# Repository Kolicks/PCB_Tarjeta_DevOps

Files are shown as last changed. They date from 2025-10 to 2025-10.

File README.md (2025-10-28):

# ⚙️ PCB_Tarjeta_DevOps
**Generic Development Console with Ethernet and USB Connectivity**

---

<p align="center">
  <a href="https://github.com/Kolicks/PCB_Tarjeta_DevOps" target="_blank">
    
  </a>
</p>

---

## 📘 Overview
**PCB_Tarjeta_DevOps** is a versatile, custom-designed console PCB created primarily as a **personal exercise in complex two-layer design and Ethernet integration**.  
It serves as a **general-purpose development board** adapted from the **ST Nucleo-F412ZG** design, focusing on practical layout challenges and signal-integrity learning (Ethernet, differential pairs, impedance control).

<p align="center">
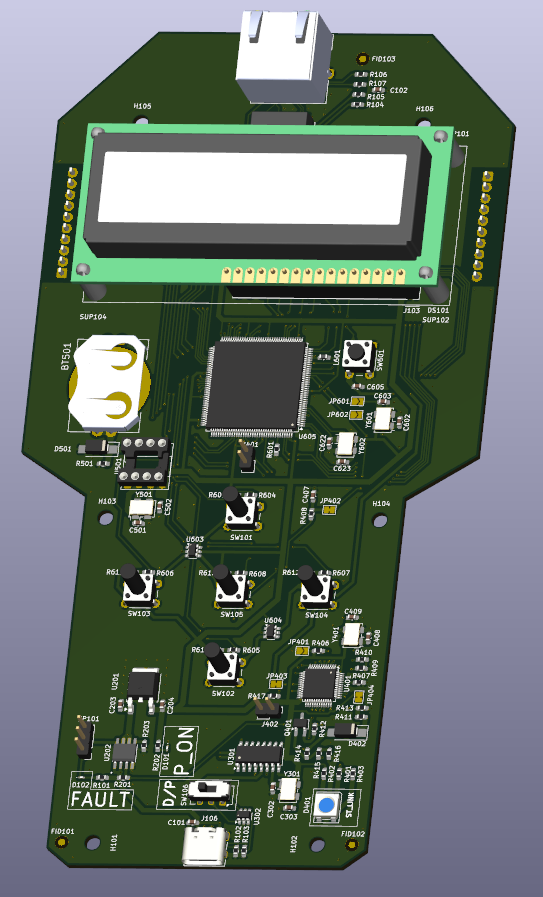
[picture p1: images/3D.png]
3D Top
  
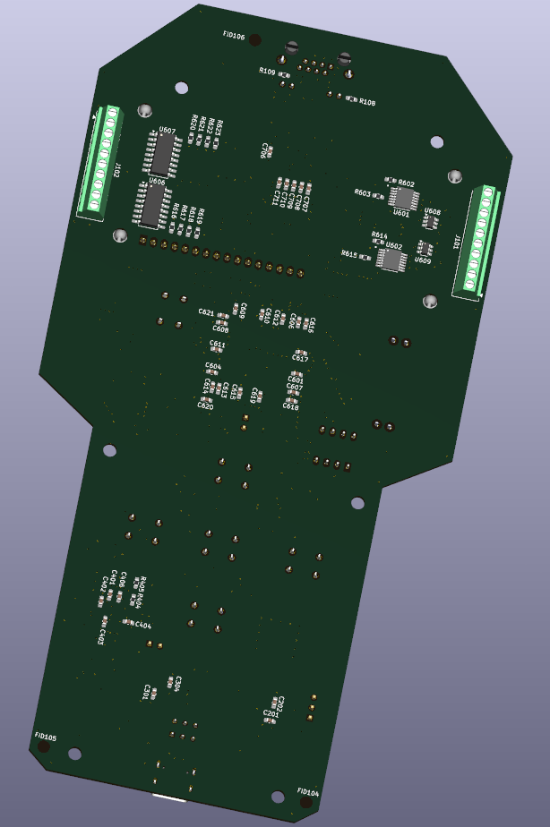
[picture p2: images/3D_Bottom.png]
3D Bottom
  
  <br>
  <em>3D renders of the PCB_Tarjeta_DevOps — Top and Bottom views</em>
</p>

---

## ⚙️ General Information
- A **general-purpose console**, not intended for a specific application.  
- Designed as a **learning exercise**, implementing many components on only **two layers** to increase design difficulty.  
- Served as an **introduction to Ethernet PCB layout**, including **differential pair routing** and **impedance control**.  
- Several schematic blocks were **adapted from the ST Nucleo-F412ZG** for familiarity and reference.  

<p align="center">
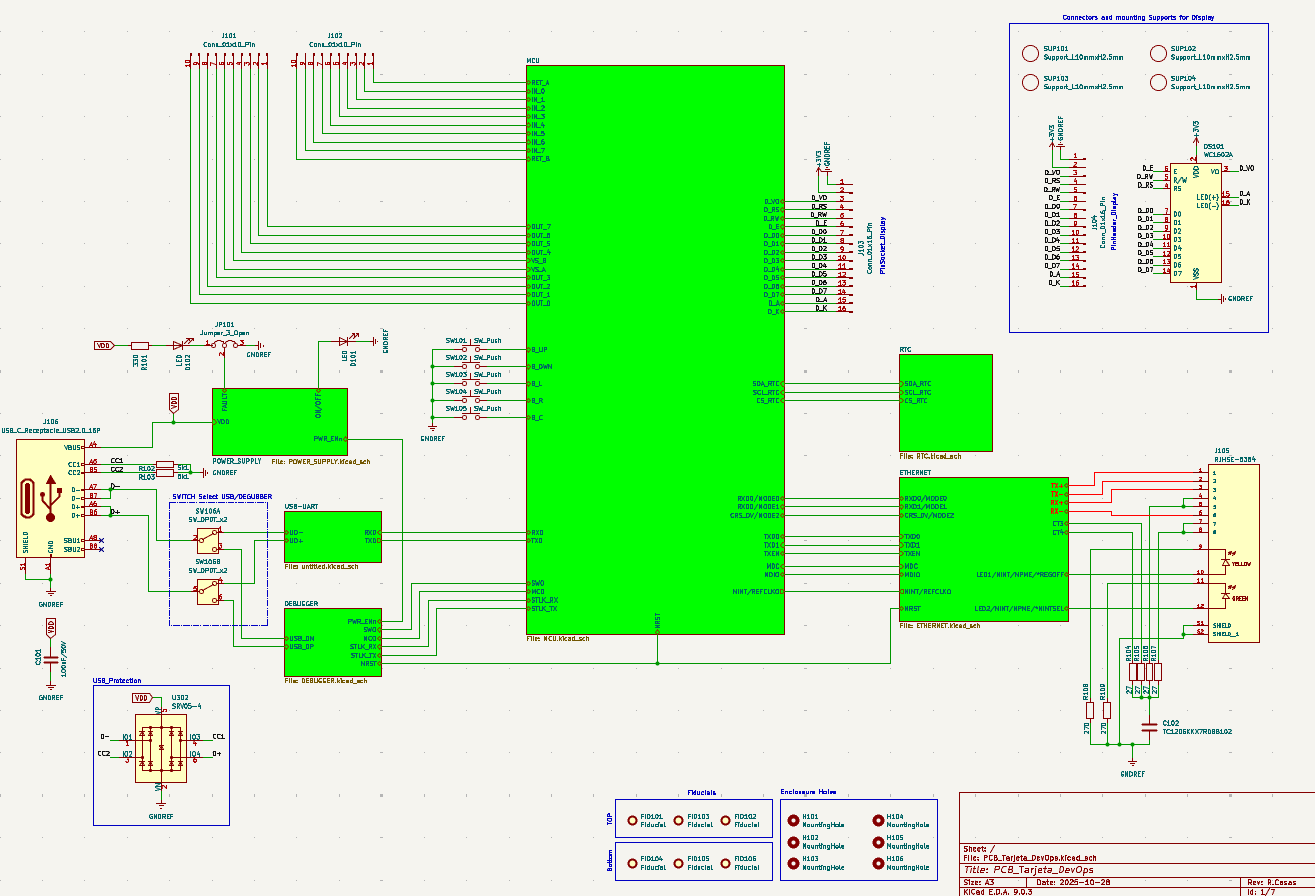
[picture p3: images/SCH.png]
Schematic
  
  <br>
  <em>Full schematic diagram of the PCB_Tarjeta_DevOps (KiCad 9)</em>
</p>

---

## 🔧 Characteristics
- Acts as a **multi-purpose development console**.  
- Supports **USB power and programming**.  
- Integrates **Ethernet connectivity** with differential pair routing and impedance matching.  
- Includes **8 Inputs and 8 Outputs**:  
  - **Outputs for industrial/power use** driven by **ITS4090QEPDXUMA1** — up to **1.5 A** each, suitable for **24 V industrial control**.  
  - **8 isolated outputs** using **TLP290-4** optocouplers (potential-free, up to 24 V).  
- Features a **hardware switch selector** to toggle between **programming** and **debugging** modes.  
- Includes a **real-time clock (RTC)** with **CR2032 battery backup**.  
- Provides **five tactile buttons** for user interaction with the display or user interface.  

<p align="center">
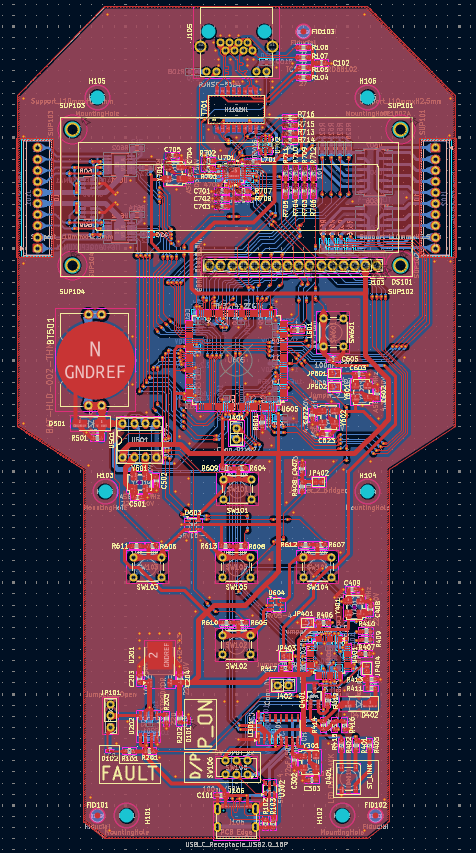
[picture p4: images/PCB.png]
PCB Layout
  
  <br>
  <em>Top layer routing and overall PCB layout (KiCad 9)</em>
</p>

---

## ⚠️ Design Notes
- **Display Section:**  
  - Multiple components in the display area require mechanical supports and connectors.  
  - Some footprints should be marked as **DNP (Do Not Populate)** and clearly specified for **DFM/DFA** purposes.  
- **Ethernet Interface:**  
  - Differential pairs are **impedance-matched to 100 Ω**, validated using **JLCPCB’s impedance calculator** and fabrication stack-up data.  
  - **USB traces** are not impedance-controlled in this revision (planned improvement).  
- **DFM Analysis (JLCPCB DFM tool):**  
  - Found **drilling overlaps** in display-related holes (mechanical supports and signals).  
  - **USB-C footprint issue:** plated hole size **0.60 mm, required >0.61 mm** tolerance.  
- **Silkscreen and Drill Issues:**  
  - Some silkscreen elements **collide with through holes** but remain legible.  
  - **Line width warnings** flagged for narrow silkscreen traces — minor fabrication risk, acceptable in prototype runs.  
- Overall design remains **manufacturable** and **functionally valid**, despite minor DFM flags.  

---

## 🧩 Repository Structure
PCB_Tarjeta_DevOps/

├── schematic/ # KiCad schematic files

├── pcb_layout/ # KiCad PCB layout files

├── gerbers/ # Gerber fabrication files

├── images/ # Rendered visuals (3D, SCH, PCB)

├── LICENSE # Hardware license (CERN-OHL-P v2.0)

└── README.md # Project documentation

---

## 📜 License
This hardware design is released under the **CERN Open Hardware License v2 – Permissive (CERN-OHL-P-2.0)**.  
You are free to use, modify, and distribute this design, provided that:
- The license is included with redistributions.
- Proper credit is given to the original author.

More info: https://cern-ohl.web.cern.ch/

---

## 👤 Author
**Project:** PCB_Tarjeta_DevOps  
**Author:** [Kolicks]  
**Toolchain:** KiCad 9  
**Version:** 9.0  

---

## 🧱 Future Improvements
- Redesign **USB differential pair** routing with impedance control.  
- Correct **DFM-related drilling and silkscreen** warnings.  
- Mark **DNP parts** for display connectors and update BOM.

---

⭐ *If you find this project useful or educational, please consider starring the repository and sharing feedback!*

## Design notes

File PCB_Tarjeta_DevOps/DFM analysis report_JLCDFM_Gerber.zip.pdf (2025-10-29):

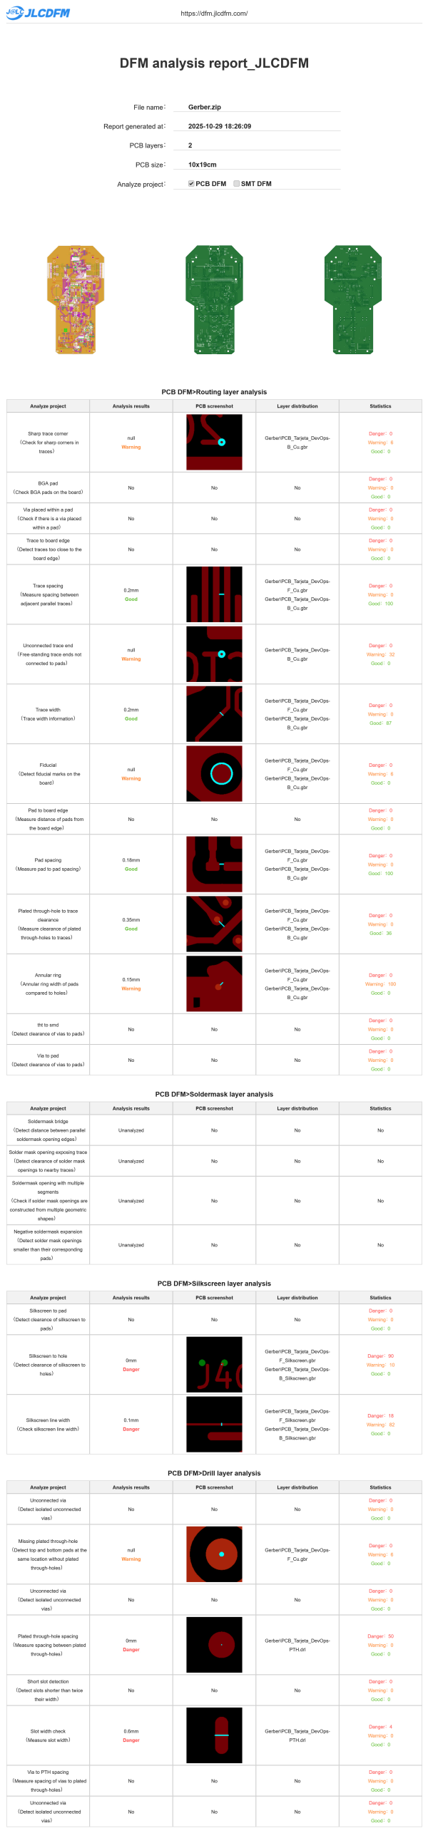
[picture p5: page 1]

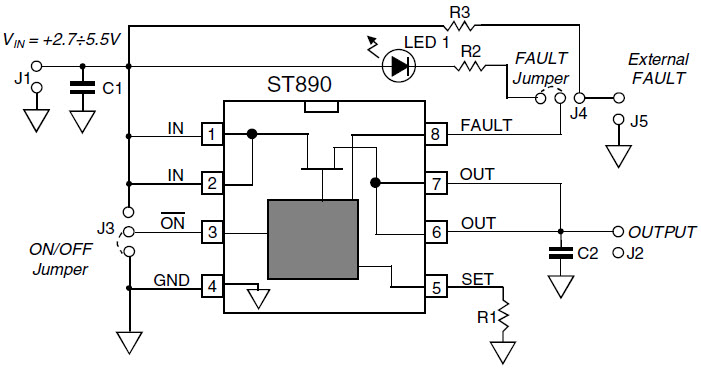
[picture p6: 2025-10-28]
PCB_Tarjeta_DevOps/Datasheets/an1441_fig.13.jpg

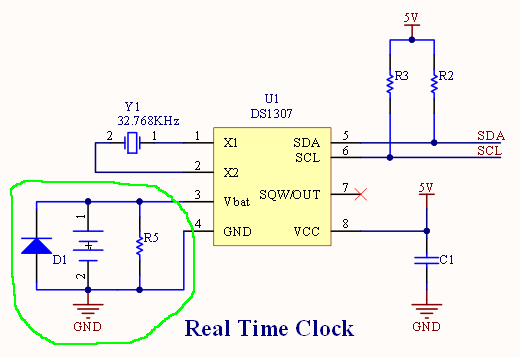
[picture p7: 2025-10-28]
PCB_Tarjeta_DevOps/Datasheets/8383d035b52fffc298dc10fdf3a309924005adde.png

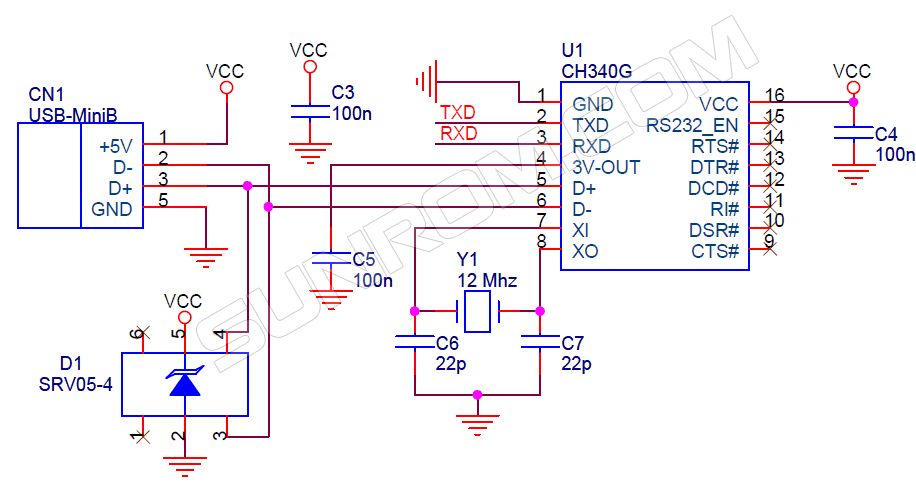
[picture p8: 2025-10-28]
PCB_Tarjeta_DevOps/Datasheets/ch340.gif

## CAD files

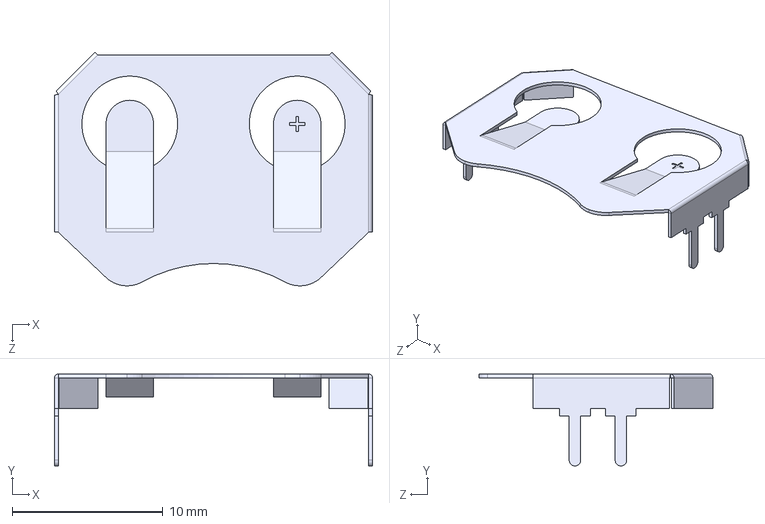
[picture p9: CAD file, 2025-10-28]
PCB_Tarjeta_DevOps/Footprints/BAT_HLD_002_THM/BAT-HLD-002-THM.step
21.1 x 6.10 x 15.5 mm

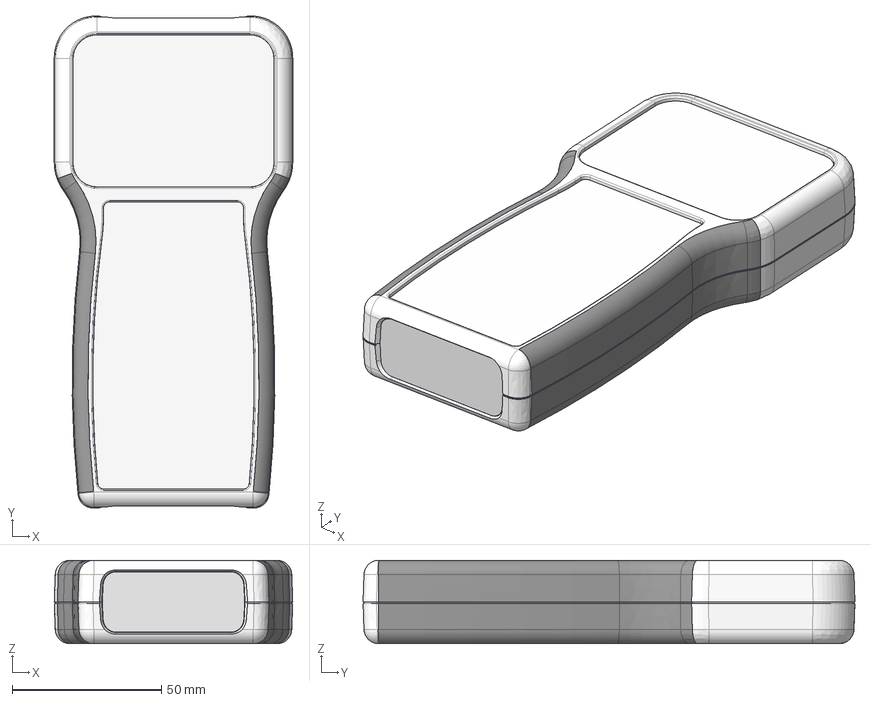
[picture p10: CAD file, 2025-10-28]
PCB_Tarjeta_DevOps/Footprints/Box_1553TTBK/1553TT.stp
80.0 x 165.0 x 28.0 mm
1553TT BOTTOM
1553TT TOP
1553TT FRONT PANEL x 2
1553TT PCB
SC501 (screw M3-0.5X 18mm FH) x 6
M3 PLASTIC INSERT (SERIES 19 LONG) x 6
1553TT TOP GRIP
1553TT BOTTOM GRIP

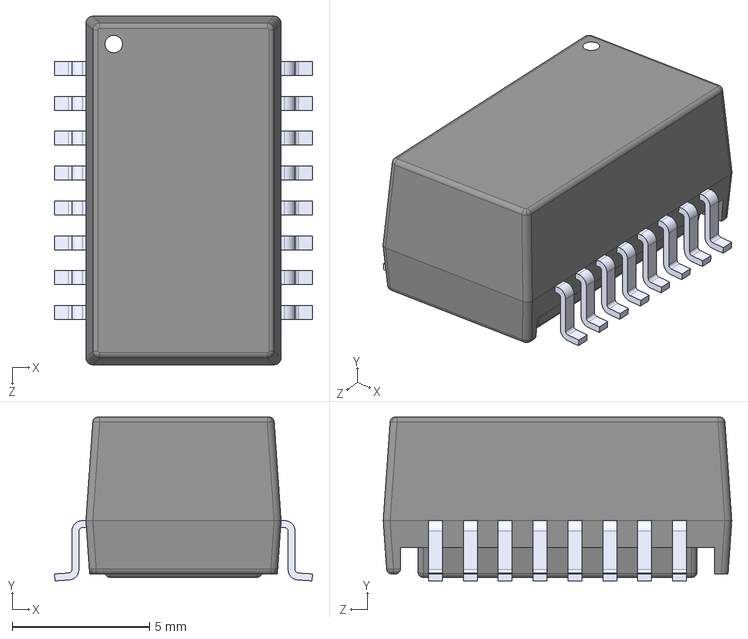
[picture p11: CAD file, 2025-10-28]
PCB_Tarjeta_DevOps/Footprints/H1102NL/H1102NL.step
9.40 x 5.97 x 12.7 mm

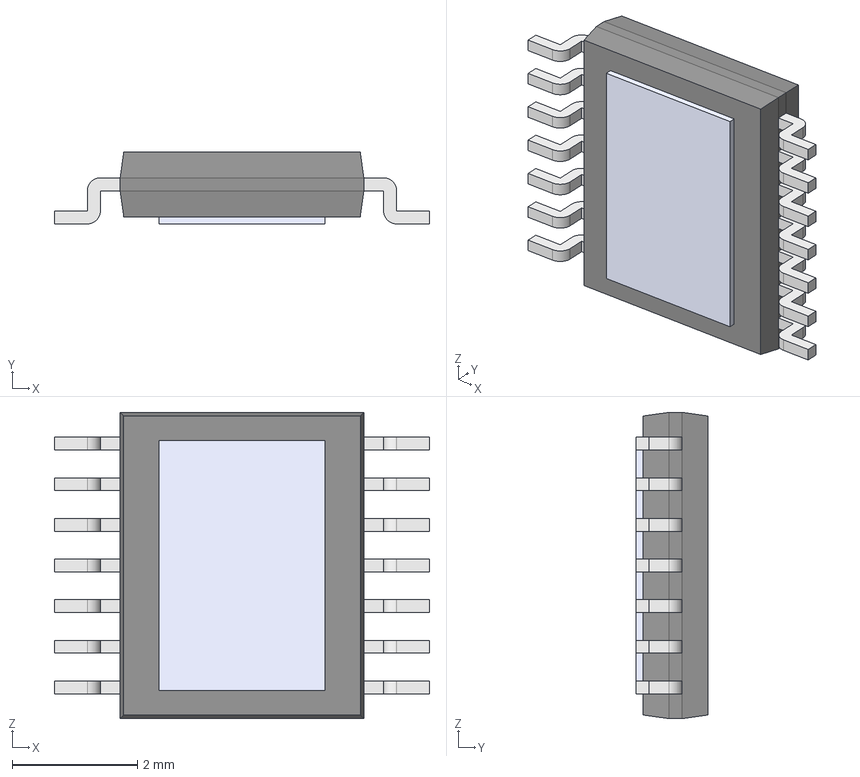
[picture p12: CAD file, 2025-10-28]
PCB_Tarjeta_DevOps/Footprints/ITS4090QEPDXUMA1/ITS4090QEPDXUMA1.step
6.00 x 1.15 x 4.90 mm
Body001 (Mirror #1) x 7
XY-plane x 12
X-axis x 12

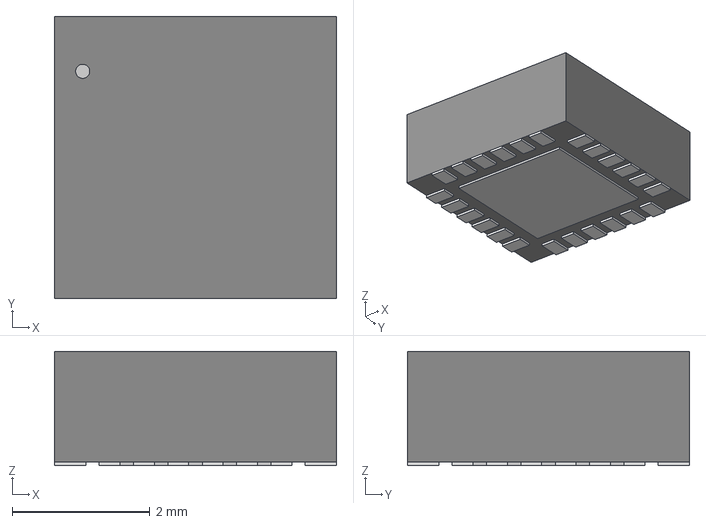
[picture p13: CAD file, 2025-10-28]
PCB_Tarjeta_DevOps/Footprints/LAN8742A_CZ_TR/SQFN24_4X4MC_MCH.step
4.09 x 4.09 x 1.65 mm

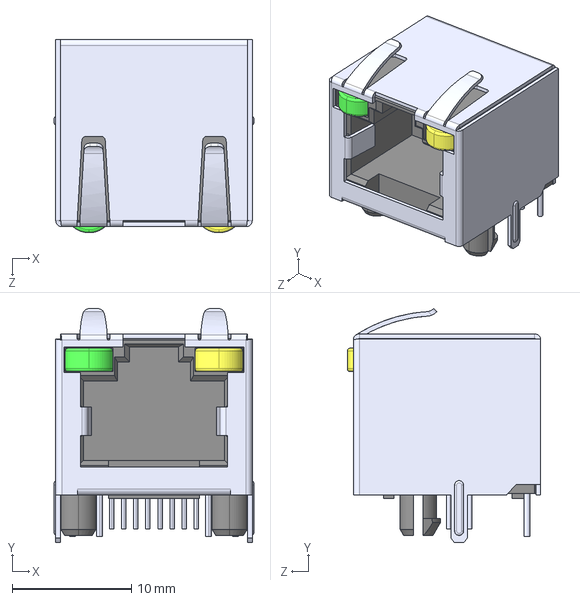
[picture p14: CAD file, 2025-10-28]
PCB_Tarjeta_DevOps/Footprints/RJHSE5384/RJHSE-5384.step
16.8 x 19.7 x 16.3 mm

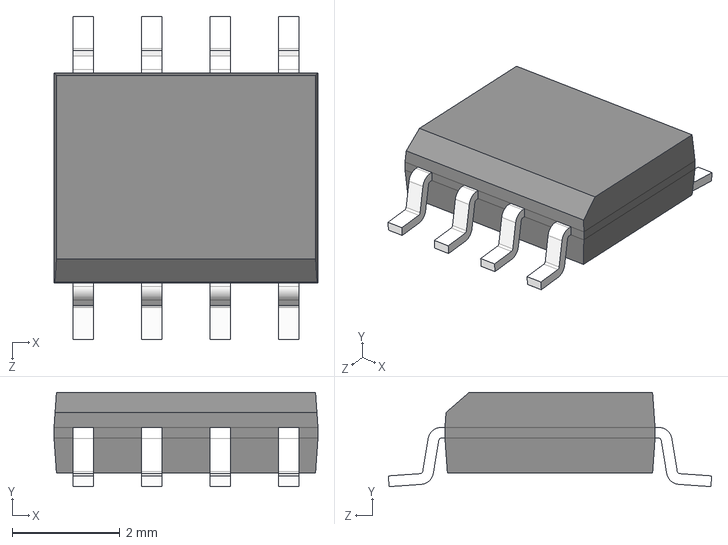
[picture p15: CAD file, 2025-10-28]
PCB_Tarjeta_DevOps/Footprints/ST890CDR/ST890CDR.step
4.90 x 1.75 x 6.00 mm

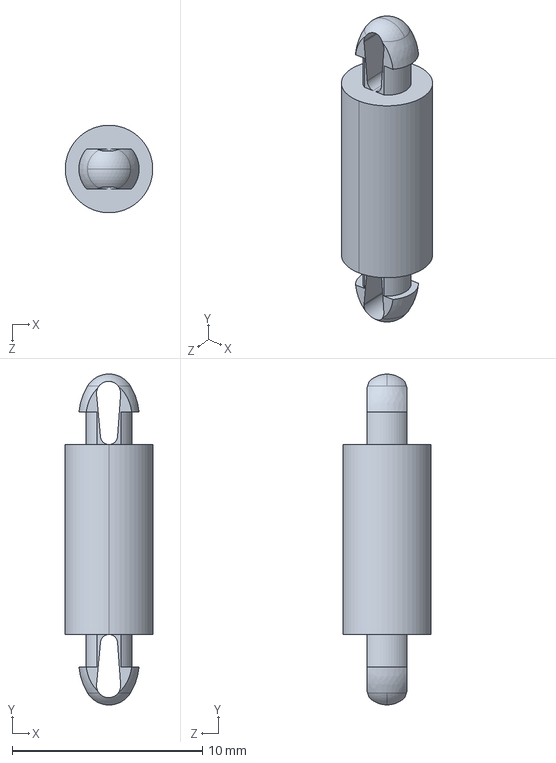
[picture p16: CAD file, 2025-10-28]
PCB_Tarjeta_DevOps/Footprints/MDLSP1_10M_01/10015254.step
4.60 x 17.4 x 4.60 mm

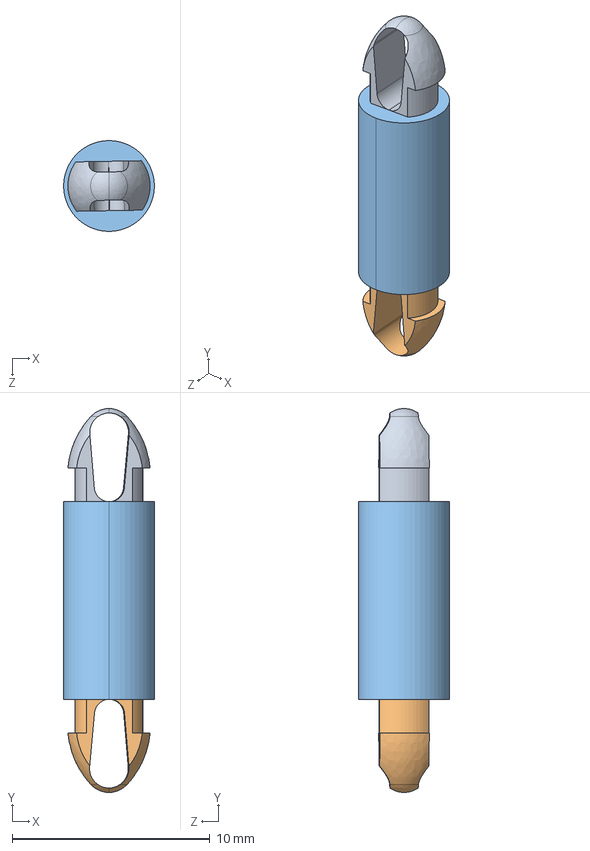
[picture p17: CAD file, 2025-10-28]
PCB_Tarjeta_DevOps/Footprints/MDLSP2_10M_01/10015582.step
4.60 x 19.4 x 4.60 mm

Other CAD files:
PCB_Tarjeta_DevOps/Footprints/Box_1553TTBK/1553TT.dwg
PCB_Tarjeta_DevOps/Footprints/Box_1553TTBK/1553TT.dxf
PCB_Tarjeta_DevOps/Footprints/Box_1553TTBK/1553TT.igs

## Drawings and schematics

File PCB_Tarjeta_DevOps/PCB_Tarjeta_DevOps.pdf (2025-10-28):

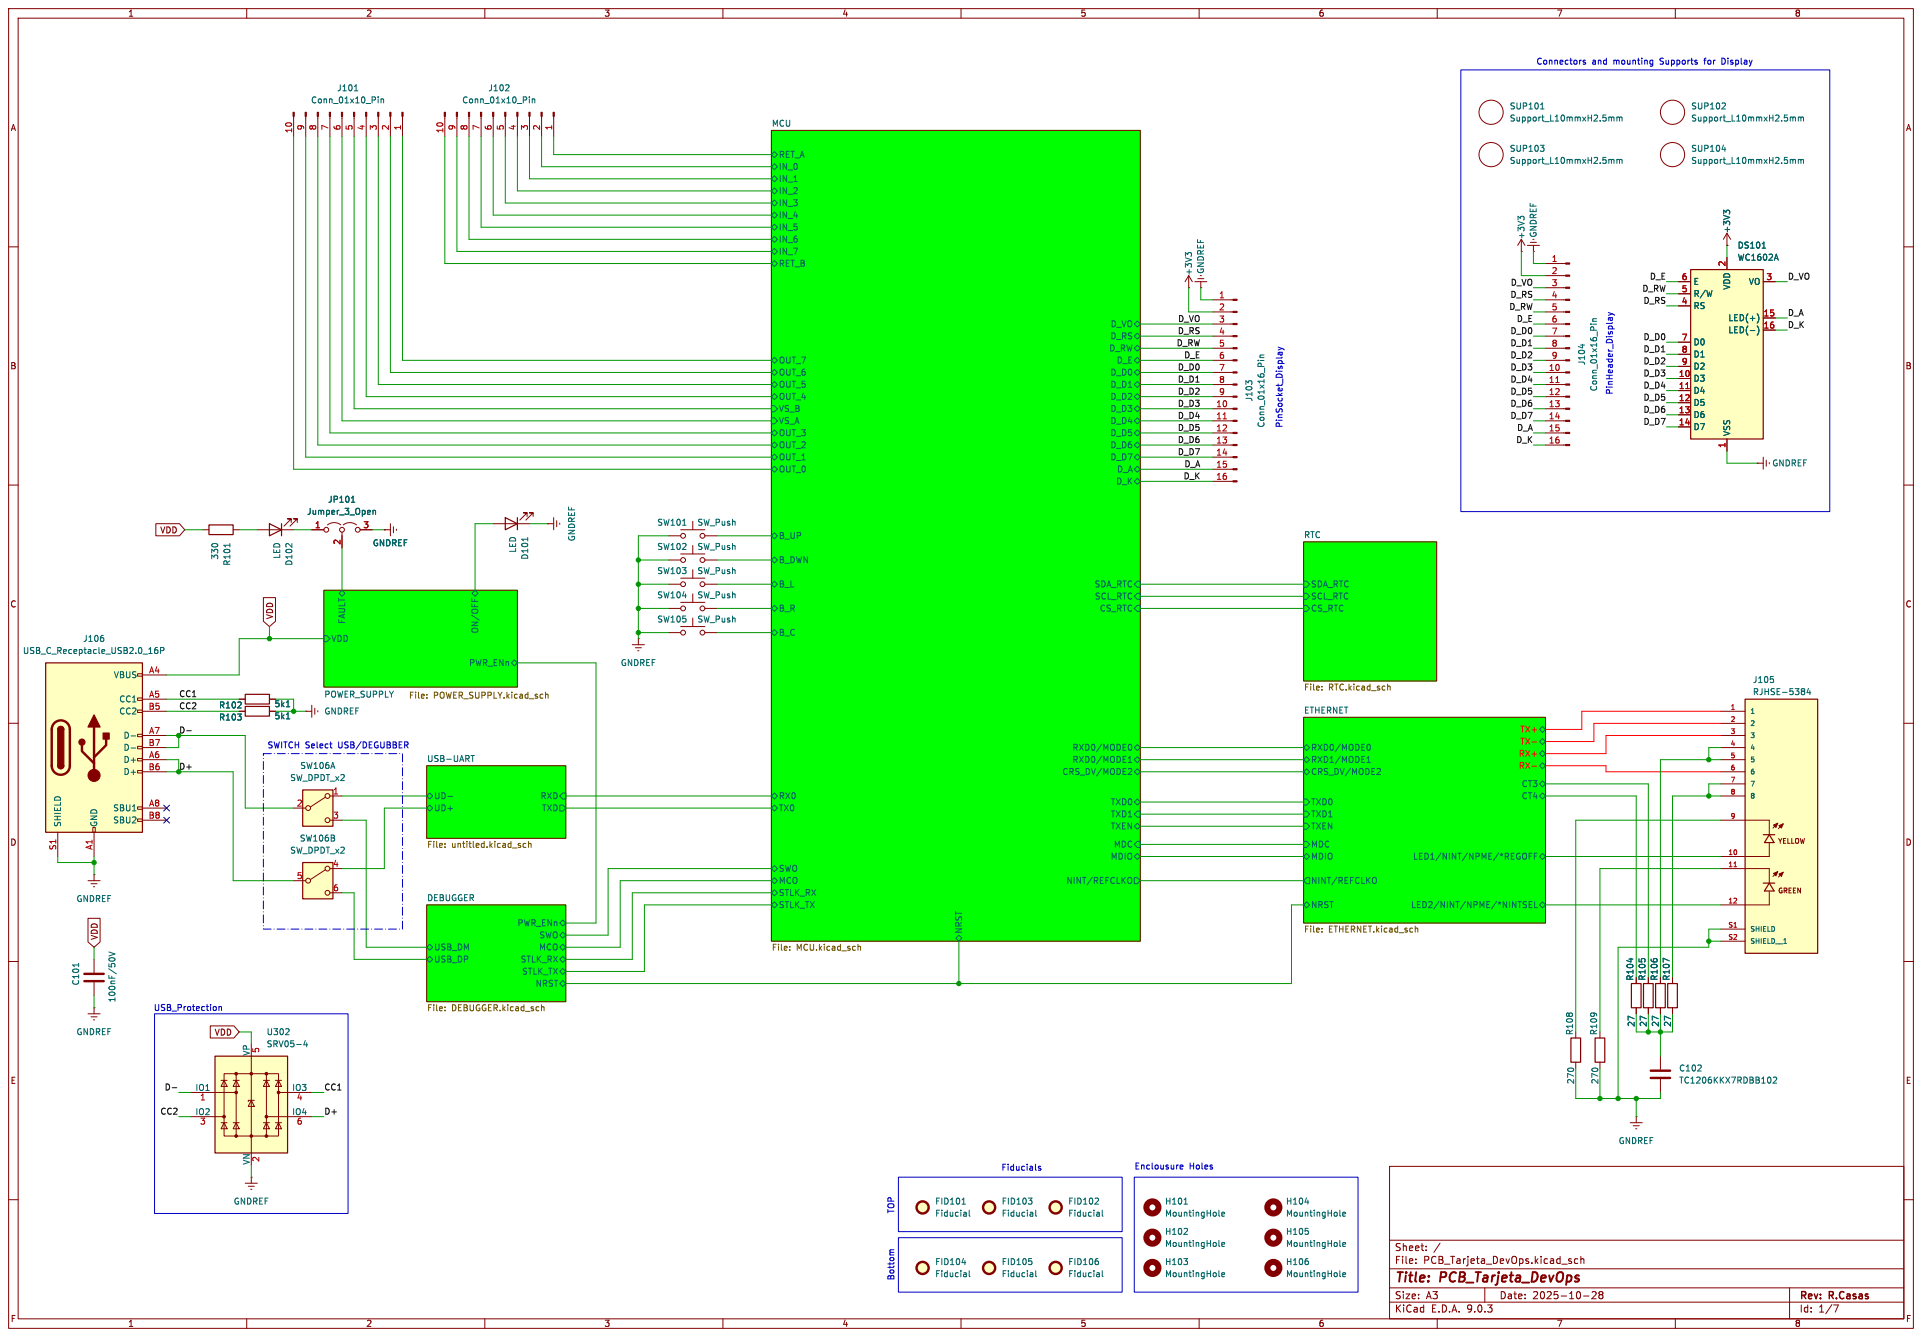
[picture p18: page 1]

LED1/NINT/NPME/*REGOFFCT4 TX+ CT3 TX- RX+ RX- NINT/REFCLKO
RXD0/MODE0 CRS_DV/MODE2 TXD0 MDIO

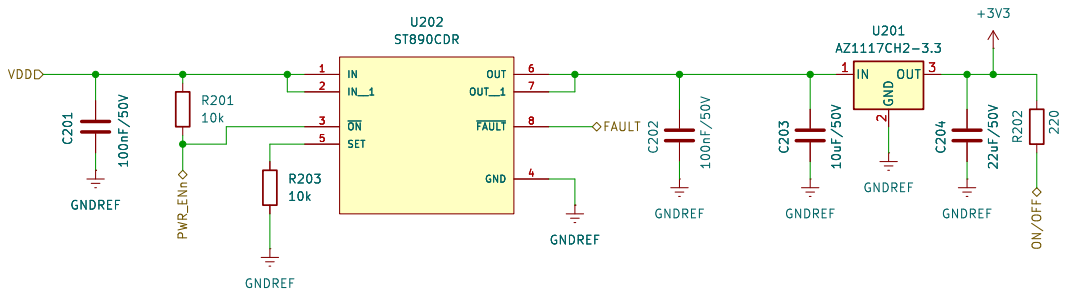
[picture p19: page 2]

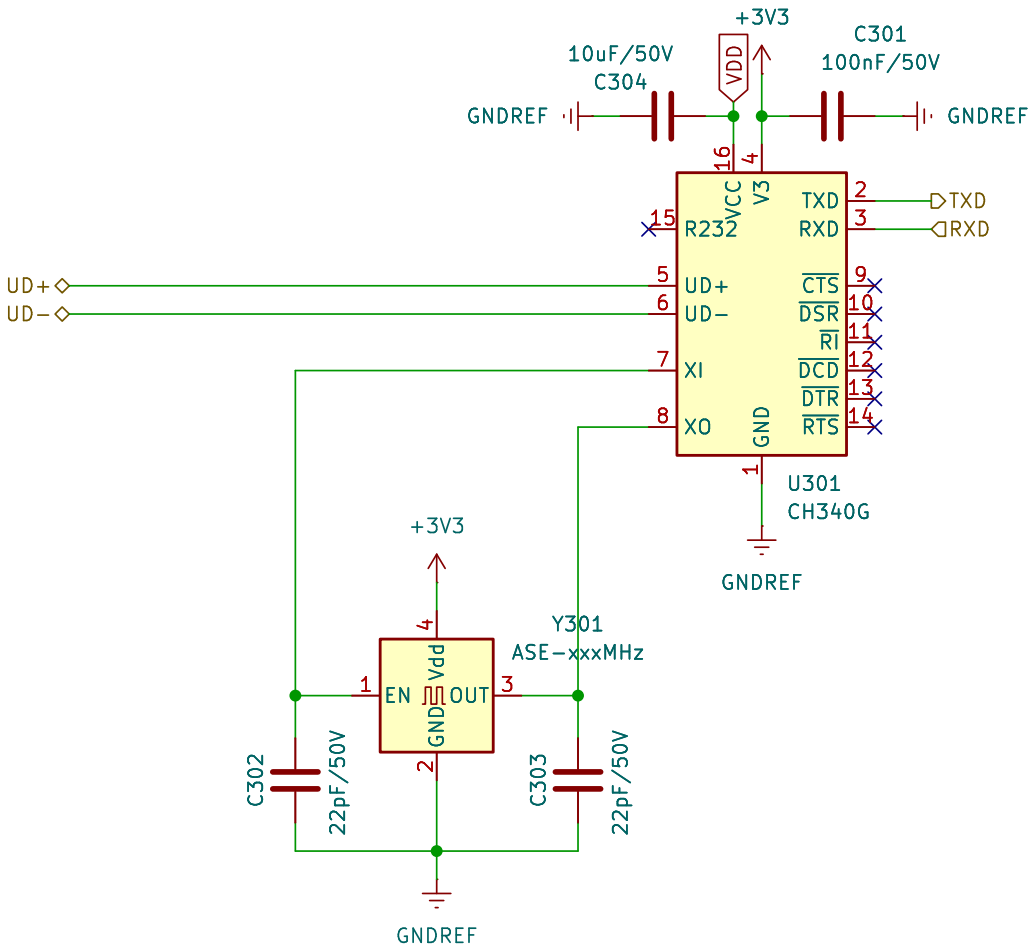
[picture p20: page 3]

1 TXD 2 RXD 3 ~{CTS}9 ~{DSR} 10 ~{RI} 11 ~{DCD} 12 ~{DTR} 13 ~{RTS} 14 GNDREF C303 22pF/50V

1 TXD 2 RXD 3 ~{CTS}9 ~{DSR} 10 ~{RI} 11 ~{DCD} 12 ~{DTR} 13 ~{RTS} 14 U301 CH340G

File: untitled.kicad_sch Sheet: /USB-UART/
Id: 3/7 Title: PCB_Tarjeta_DevOps

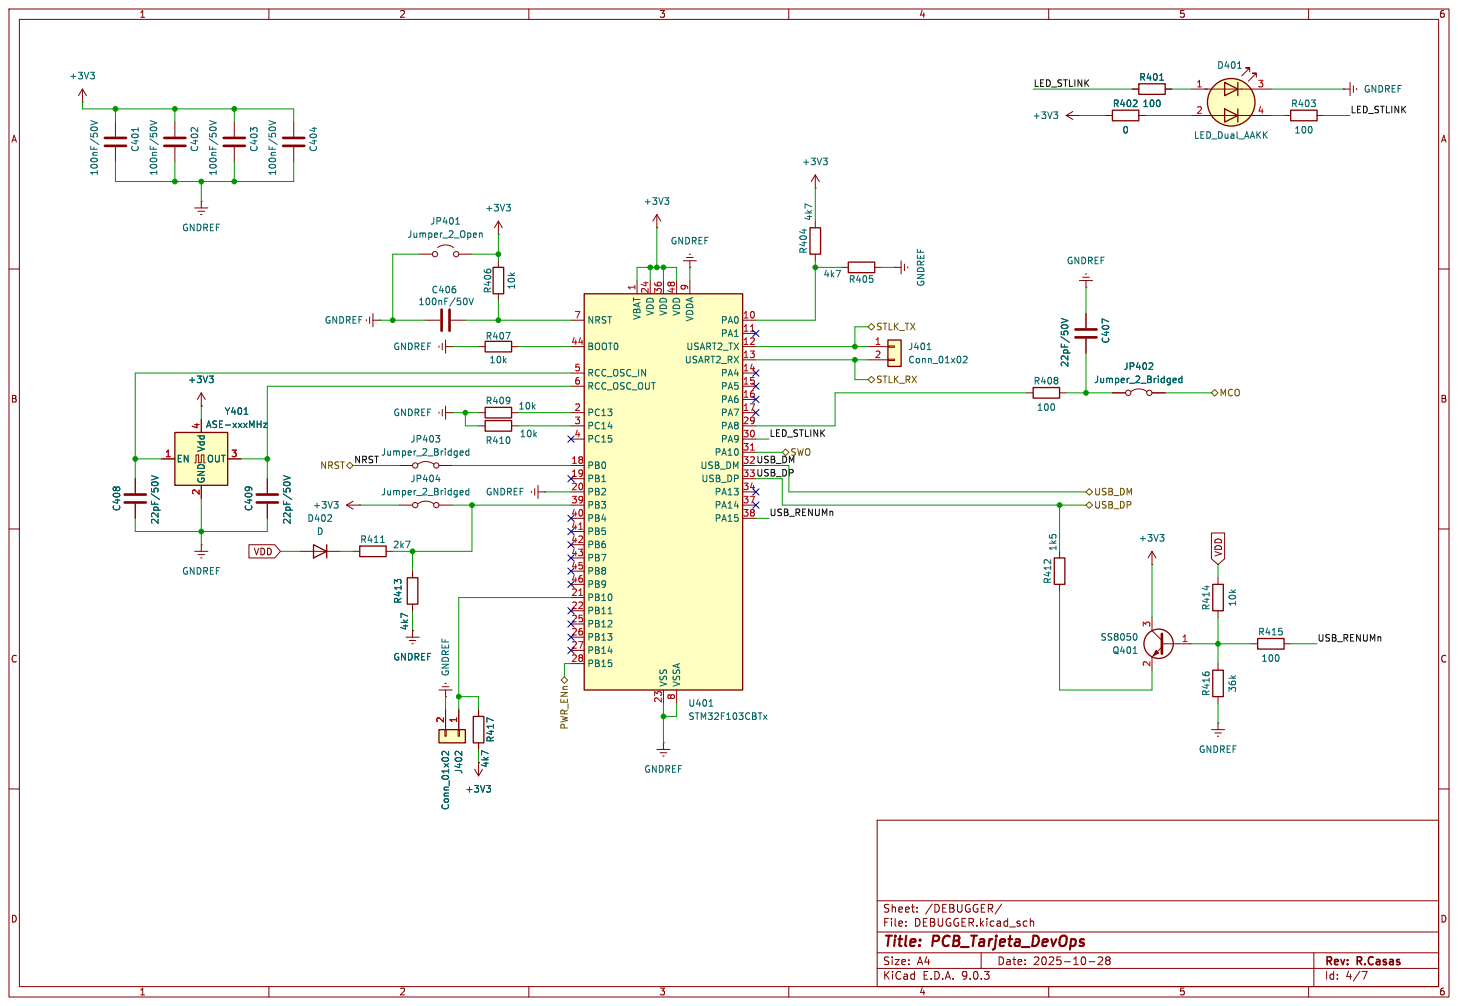
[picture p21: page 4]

1 VDD 24 VDD 36 VSS 23 VDD 48 VSSA

File: DEBUGGER.kicad_sch Sheet: /DEBUGGER/ GNDREF GNDREF

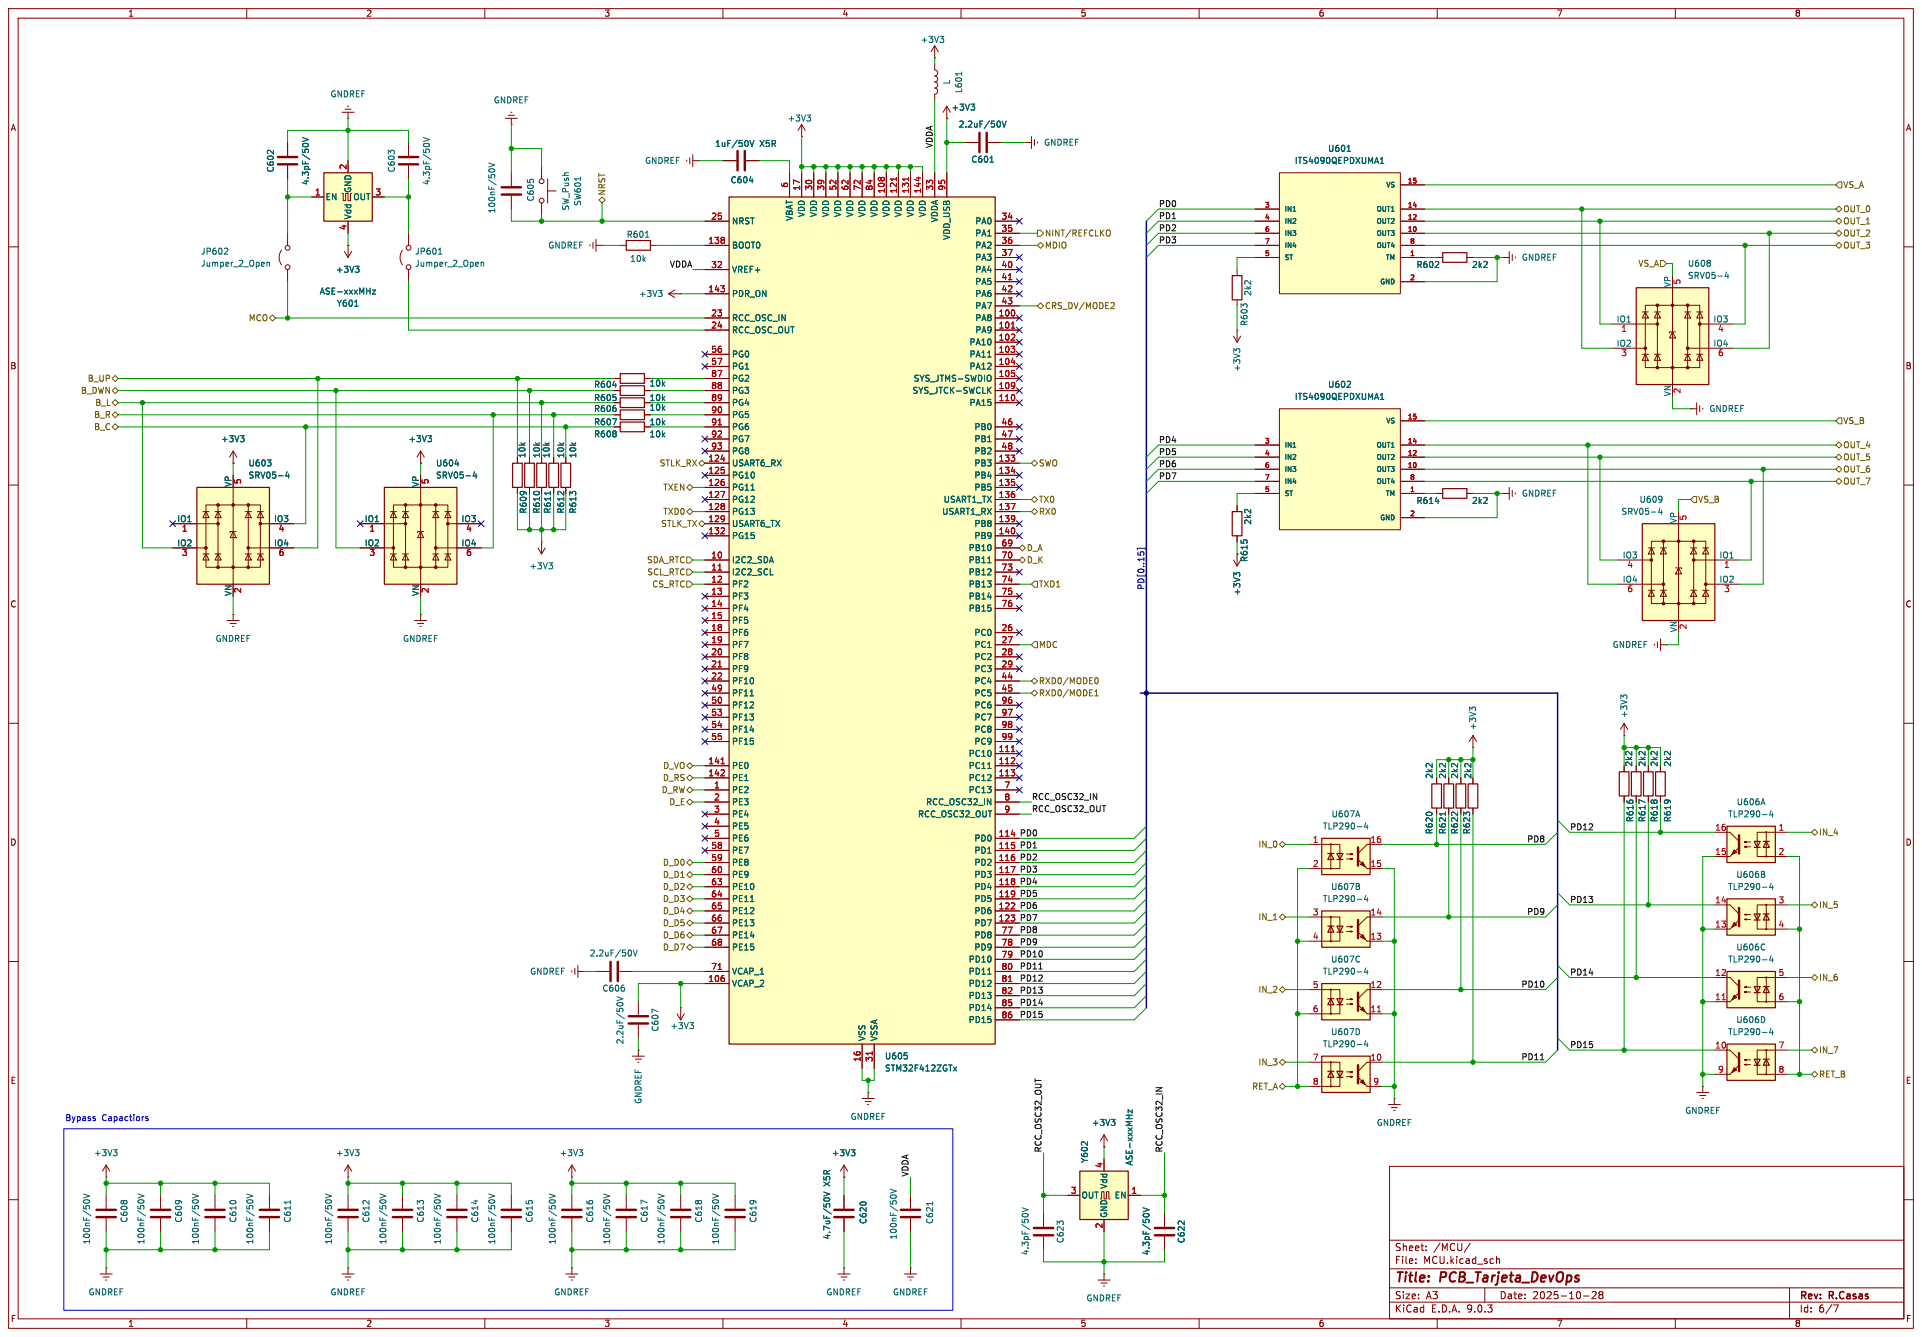
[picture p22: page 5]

6 VDD 17 VDD 30 VDD 39 VDD 52 VDD 62 VDD 72 VSS 16 VDD 84 VSSA 31 VDD 108 VDD 121 VDD 131 VDD 144 VDDA 33 VDD_USB 95 PA0 34 PA1 35 PA2 36 PA3 37 PA4 40 PA5 41 PA6 42 PA7 43 PA8 100 PA9 101 PA10 102 PA11 103 PA12 104 SYS_JTMS-SWDIO 105 SYS_JTCK-SWCLK 109 PA15 110 PB0 46 PB1 47 PB2 48 PB3 133 PB4 134 PB5 135 USART1_TX 136 USART1_RX 137 PB8 139 PB9 140 PB10 69 PB11 70 PB12 73 PB13 74 PB14 75 PB15 76 PC0 26 PC1 27 PC2 28 PC3 29 PC4 44 PC5 45 PC6 96 PC7 97 PC8 98 PC9 99 PC10 111 PC11 112 PC12 113 PC13 7 RCC_OSC32_IN 8 RCC_OSC32_OUT 9 PD0 114 PD1 115 PD2 116 PD3 117 PD4 118 PD5 119 PD6 122 PD7 123 PD8 77 PD9 78 PD10 79 PD11 80 PD12 81 PD13 82 PD14 85 PD15 86 U605 STM32F412ZGTx R610 10k GNDREF C607 +3V3 2.2uF/50V +3V3

6 VDD 17 VDD 30 VDD 39 VDD 52 VDD 62 VDD 72 VSS 16 VDD 84 VSSA 31 VDD 108 VDD 121 VDD 131 VDD 144 VDDA 33 VDD_USB 95 PA0 34 PA1 35 PA2 36 PA3 37 PA4 40 PA5 41 PA6 42 PA7 43 PA8 100 PA9 101 PA10 102 PA11 103 PA12 104 SYS_JTMS-SWDIO 105 SYS_JTCK-SWCLK 109 PA15 110 PB0 46 PB1 47 PB2 48 PB3 133 PB4 134 PB5 135 USART1_TX 136 USART1_RX 137 PB8 139 PB9 140 PB10 69 PB11 70 PB12 73 PB13 74 PB14 75 PB15 76 PC0 26 PC1 27 PC2 28 PC3 29 PC4 44 PC5 45 PC6 96 PC7 97 PC8 98 PC9 99 PC10 111 PC11 112 PC12 113 PC13 7 RCC_OSC32_IN 8 RCC_OSC32_OUT 9 PD0 114 PD1 115 PD2 116 PD3 117 PD4 118 PD5 119 PD6 122 PD7 123 PD8 77 PD9 78 PD10 79 PD11 80 PD12 81 PD13 82 PD14 85 PD15 86 C620 4.7uF/50V X5R +3V3 Y602 ASE-xxxMHz EN 1 Vdd

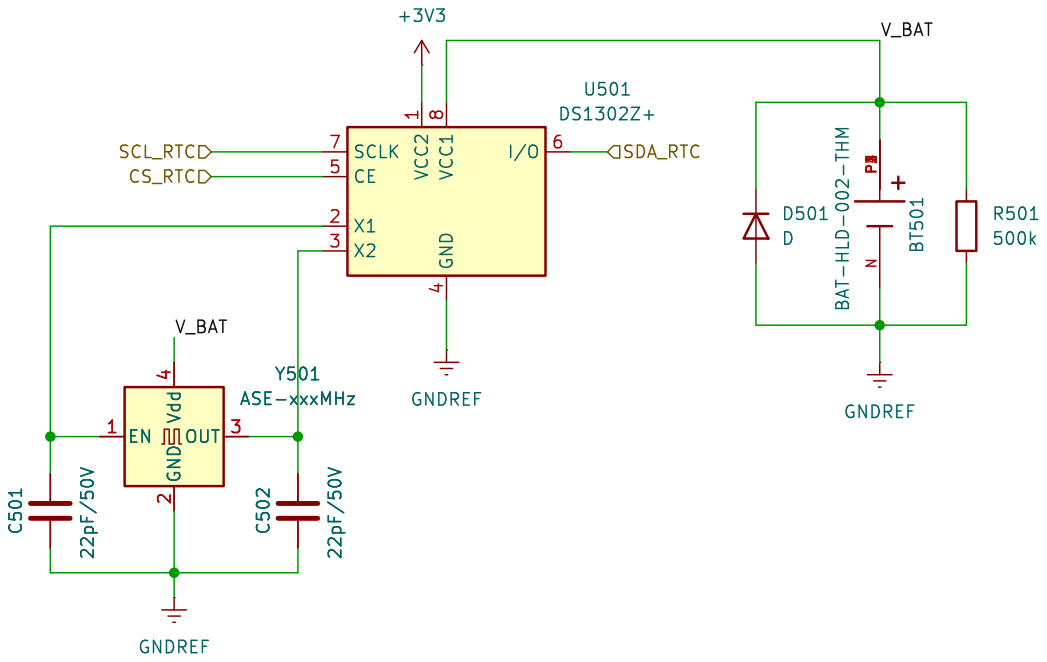
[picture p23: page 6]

2 OUT 3 Y501 ASE-xxxMHz C501 22pF/50V GNDREF D501 D GNDREF R501

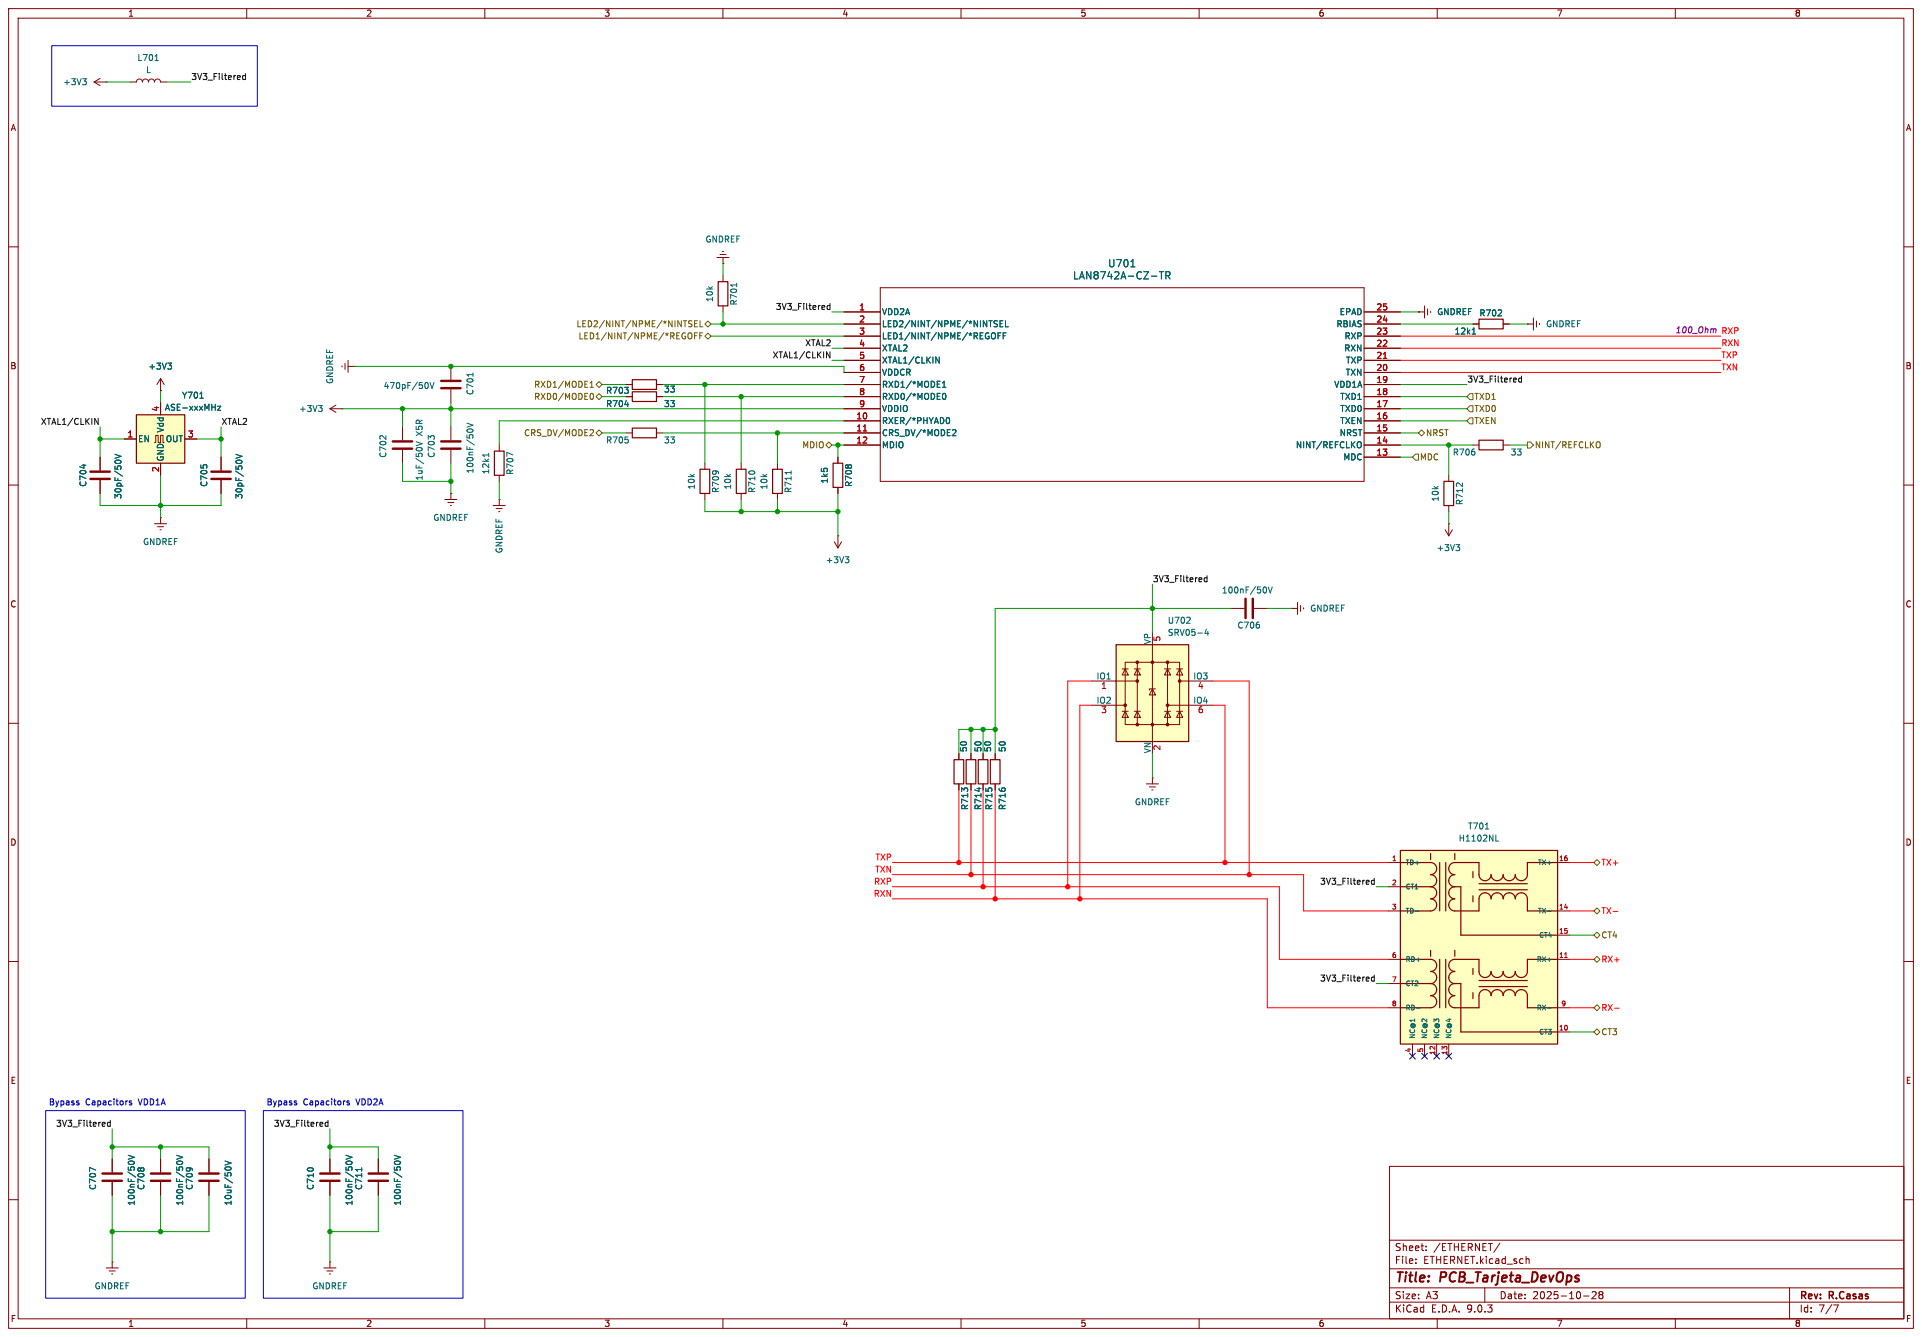
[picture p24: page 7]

2 OUT 3Y701 ASE-xxxMHz +3V3 GNDREF R715 50 R714 50 R713 50 R705 33 R704 33 R703 33 R711 10k R709 10k R710 10k

5 NC@3 12 NC@4 13 TX+ 16 TX- 14 CT4 15 RX+ 11 RX- 9 CT3 10 T701 H1102NL GNDREF

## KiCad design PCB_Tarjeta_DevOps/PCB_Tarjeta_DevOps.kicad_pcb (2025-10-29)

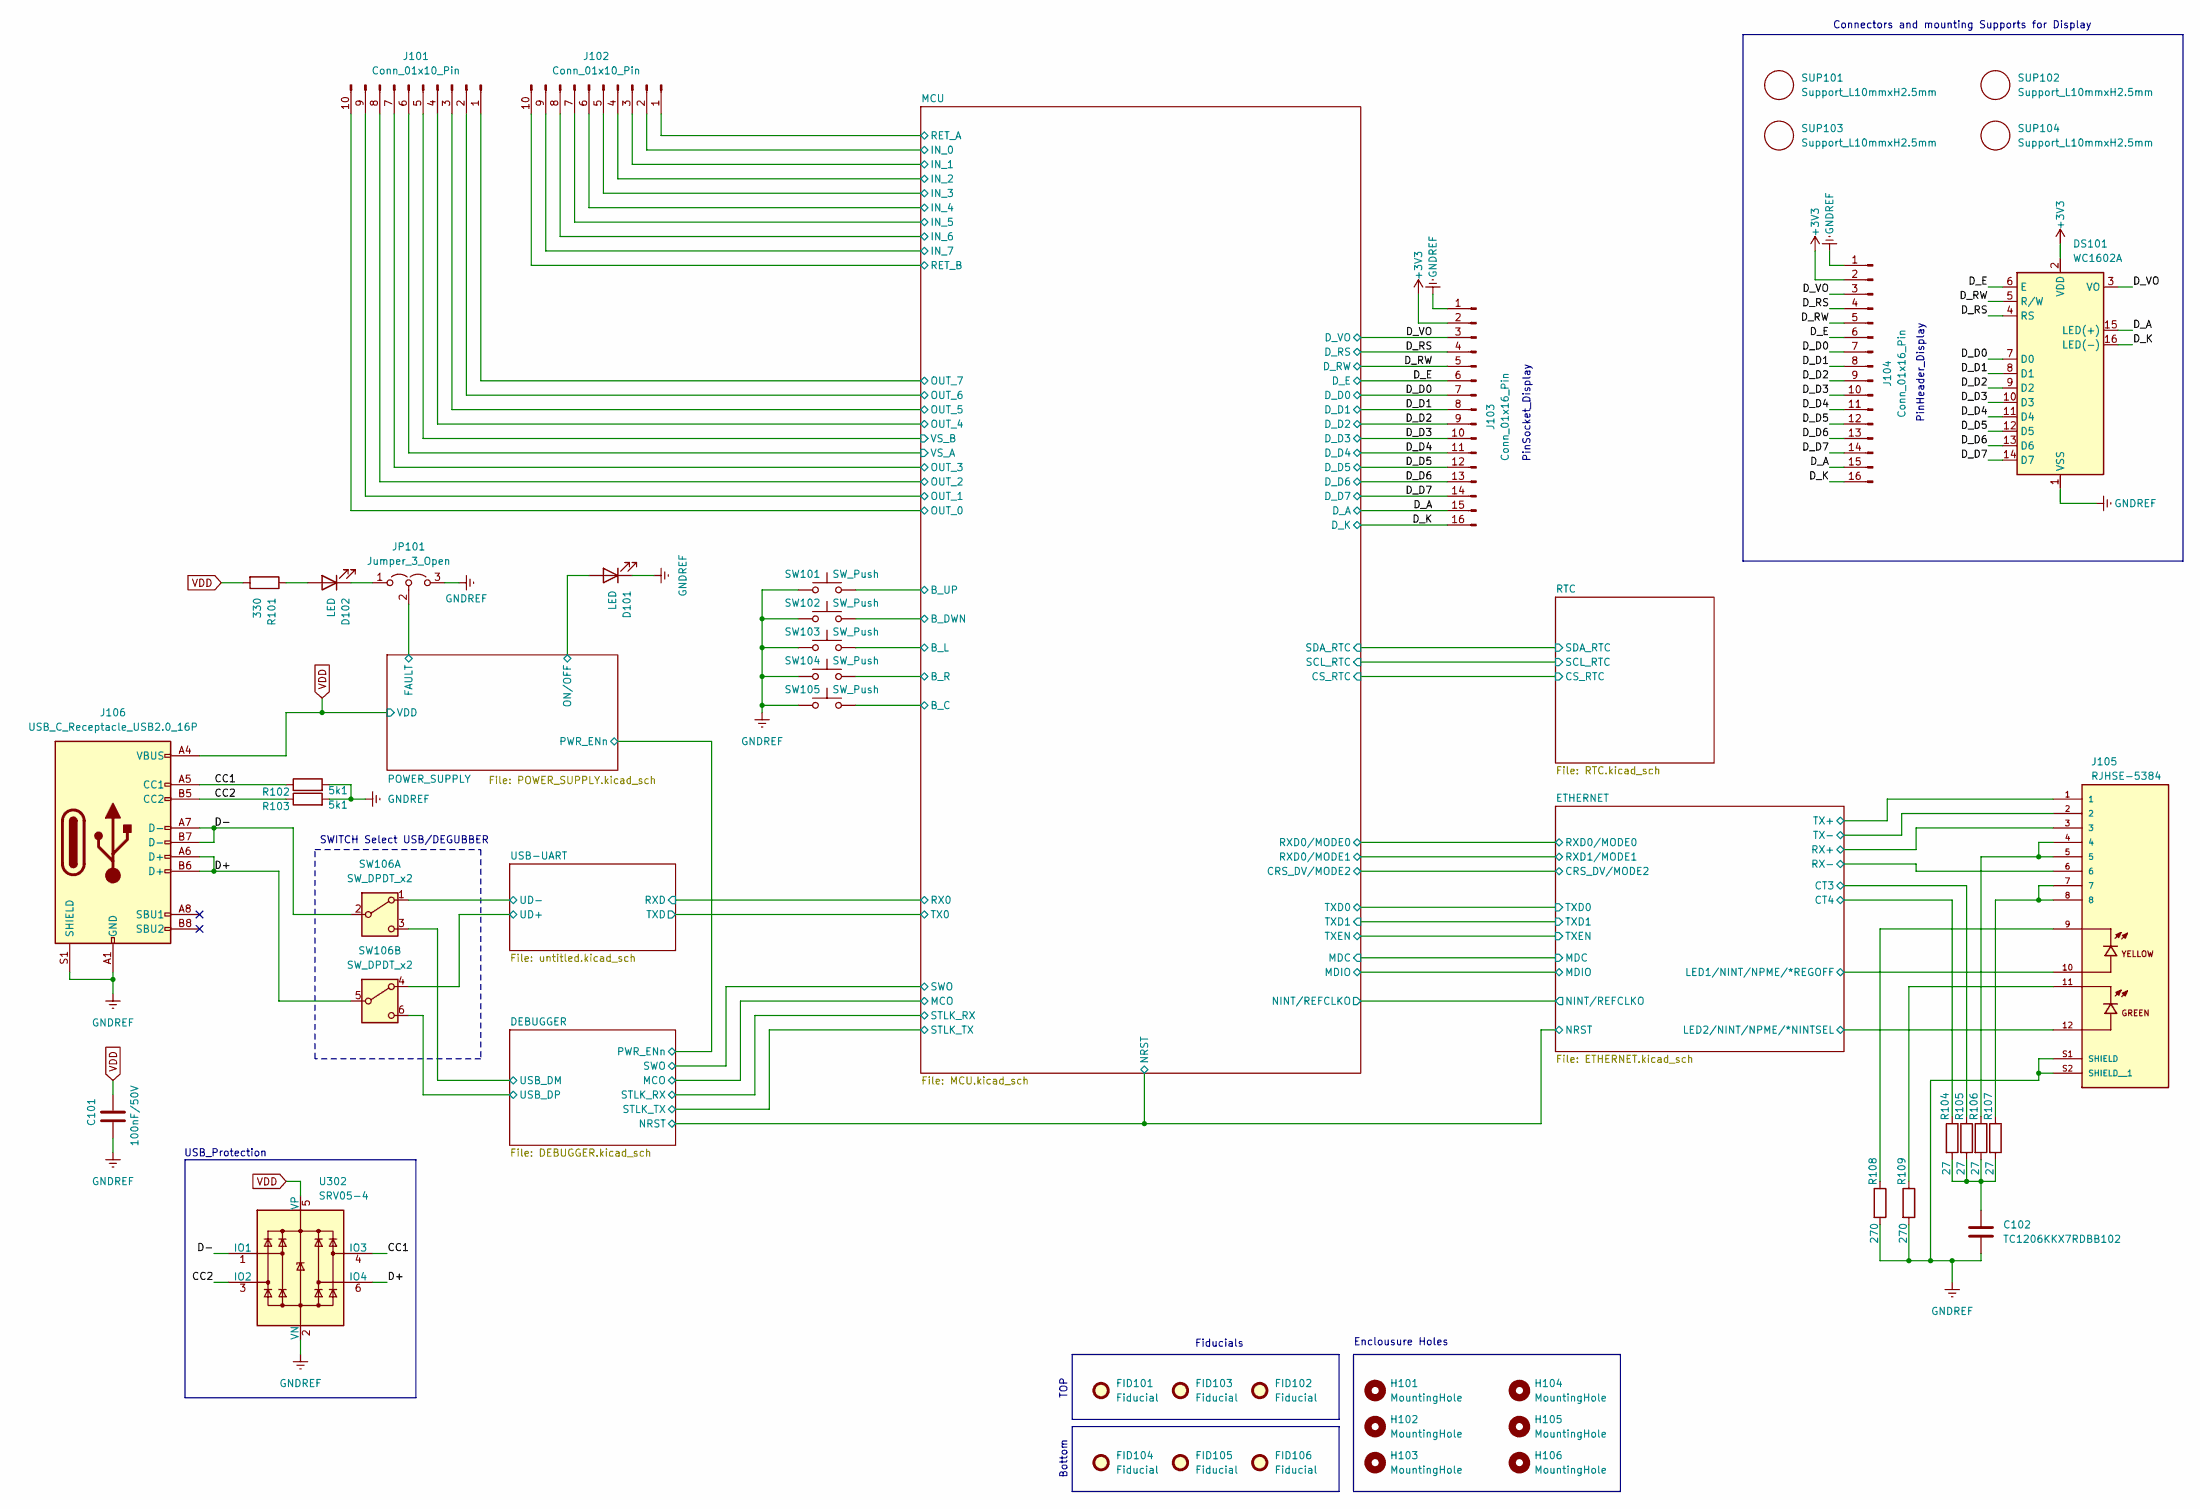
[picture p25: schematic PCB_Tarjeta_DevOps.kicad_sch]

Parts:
C101: 100nF/50V; C_0603_1608Metric_Pad1.08x0.95mm_HandSolder
C102: TC1206KKX7RDBB102; C_0603_1608Metric_Pad1.08x0.95mm_HandSolder
D101, D102: LED; LED_0201_0603Metric_Pad0.64x0.40mm_HandSolder
DS101: WC1602A
FID101, FID102, FID103, FID104, FID105, FID106: Fiducial; Fiducial_1.5mm_Mask3mm
H101, H102, H103, H104, H105, H106: MountingHole; MountingHole_3.2mm_M3_ISO14580
J101, J102: Conn_01x10_Pin; TerminalBlock_Phoenix_MPT-0,5-10-2.54_1x10_P2.54mm_Horizont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
J103: Conn_01x16_Pin; PinSocket_1x16_P2.54mm_Vertical
J104: Conn_01x16_Pin; PinHeader_1x16_P2.54mm_Vertical
J105: RJHSE-5384; AMPHENOL_RJHSE-5384; PARTREV E
J106: USB_C_Receptacle_USB2.0_16P; USB_C_Receptacle_Palconn_UTC16-G
JP101: Jumper_3_Open; PinHeader_1x03_P2.54mm_Vertical
R101: 330; R_0603_1608Metric_Pad0.98x0.95mm_HandSolder
R102, R103: 5k1; R_0603_1608Metric_Pad0.98x0.95mm_HandSolder
R104, R105, R106, R107: 27; R_0603_1608Metric_Pad0.98x0.95mm_HandSolder
R108, R109: 270; R_0603_1608Metric_Pad0.98x0.95mm_HandSolder
SUP101, SUP102, SUP103, SUP104: Support_L10mmxH2.5mm; Support_1x01_L1.0mmxH2.5mm_Vertical
SW101, SW102, SW103, SW104, SW105: SW_Push; SW_PUSH_6mm_H13mm
SW106: SW_DPDT_x2; SW_CK_JS202011CQN_DPDT_Straight
U302: SRV05-4; SOT-23-6

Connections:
+3V3: DS101.2 (VDD), J103.2, J104.2; also elsewhere on the board
/CC1: J106.A5 (CC1), R102.1, U302.4 (IO3)
/CC2: J106.B5 (CC2), R103.1, U302.3 (IO2)
/D+: J106.A6 (D+), J106.B6 (D+), SW106.5 (B), U302.6 (IO4)
/D-: J106.A7 (D-), J106.B7 (D-), SW106.2 (B), U302.1 (IO1)
/DEBUGGER/USB_DM: SW106.3 (C); also elsewhere on the board
/DEBUGGER/USB_DP: SW106.6 (C); also elsewhere on the board
/D_A: DS101.15 (LED(+)), J103.15, J104.15; also elsewhere on the board
/D_D0: DS101.7 (D0), J103.7, J104.7; also elsewhere on the board
/D_D1: DS101.8 (D1), J103.8, J104.8; also elsewhere on the board
/D_D2: DS101.9 (D2), J103.9, J104.9; also elsewhere on the board
/D_D3: DS101.10 (D3), J103.10, J104.10; also elsewhere on the board
/D_D4: DS101.11 (D4), J103.11, J104.11; also elsewhere on the board
/D_D5: DS101.12 (D5), J103.12, J104.12; also elsewhere on the board
/D_D6: DS101.13 (D6), J103.13, J104.13; also elsewhere on the board
/D_D7: DS101.14 (D7), J103.14, J104.14; also elsewhere on the board
/D_E: DS101.6 (E), J103.6, J104.6; also elsewhere on the board
/D_K: DS101.16 (LED(-)), J103.16, J104.16; also elsewhere on the board
/D_RS: DS101.4 (RS), J103.4, J104.4; also elsewhere on the board
/D_RW: DS101.5 (R/W), J103.5, J104.5; also elsewhere on the board
/D_VO: DS101.3 (VO), J103.3, J104.3; also elsewhere on the board
/ETHERNET/CT3: R105.1; also elsewhere on the board
/ETHERNET/CT4: R104.1; also elsewhere on the board
/ETHERNET/LED1/NINT/NPME/*REGOFF: J105.10; also elsewhere on the board
/ETHERNET/LED2/NINT/NPME/*NINTSEL: J105.12; also elsewhere on the board
/ETHERNET/RX+: J105.3; also elsewhere on the board
/ETHERNET/RX-: J105.6; also elsewhere on the board
/ETHERNET/TX+: J105.1; also elsewhere on the board
/ETHERNET/TX-: J105.2; also elsewhere on the board
/MCU/B_C: SW105.2; also elsewhere on the board
/MCU/B_DWN: SW102.2; also elsewhere on the board
/MCU/B_L: SW103.2; also elsewhere on the board
/MCU/B_R: SW104.2; also elsewhere on the board
/MCU/B_UP: SW101.2; also elsewhere on the board
/MCU/IN_0: J102.2; also elsewhere on the board
/MCU/IN_1: J102.3; also elsewhere on the board
/MCU/IN_2: J102.4; also elsewhere on the board
/MCU/IN_3: J102.5; also elsewhere on the board
/MCU/IN_4: J102.6; also elsewhere on the board
/MCU/IN_5: J102.7; also elsewhere on the board
/MCU/IN_6: J102.8; also elsewhere on the board
/MCU/IN_7: J102.9; also elsewhere on the board
/MCU/OUT_0: J101.10; also elsewhere on the board
/MCU/OUT_1: J101.9; also elsewhere on the board
/MCU/OUT_2: J101.8; also elsewhere on the board
/MCU/OUT_3: J101.7; also elsewhere on the board
/MCU/OUT_4: J101.4; also elsewhere on the board
/MCU/OUT_5: J101.3; also elsewhere on the board
/MCU/OUT_6: J101.2; also elsewhere on the board
/MCU/OUT_7: J101.1; also elsewhere on the board
/MCU/RET_A: J102.1; also elsewhere on the board
/MCU/RET_B: J102.10; also elsewhere on the board
/MCU/VS_A: J101.6; also elsewhere on the board
/MCU/VS_B: J101.5; also elsewhere on the board
/POWER_SUPPLY/FAULT: JP101.2 (C); also elsewhere on the board
/POWER_SUPPLY/ON/OFF: D101.2 (A); also elsewhere on the board
/USB-UART/UD+: SW106.4 (A); also elsewhere on the board
/USB-UART/UD-: SW106.1 (A); also elsewhere on the board
GNDREF: C101.2, C102.2, D101.1 (K), DS101.1 (VSS), J103.1, J104.1, J105.S1 (SHIELD), J105.S2 (SHIELD__1), J106.A1 (GND), J106.A12 (GND), J106.B1 (GND), J106.B12 (GND), J106.S1 (SHIELD), JP101.3 (B), R102.2, R103.2, R108.2, R109.2, SW101.1, SW102.1, SW103.1, SW104.1, SW105.1, U302.2 (VN); also elsewhere on the board
unnamed: C102.1, R104.2, R105.2, R106.2, R107.2
unnamed: D102.2 (A), R101.1
unnamed: D102.1 (K), JP101.1 (A)
unnamed: J105.4, J105.5, R106.1
unnamed: J105.7, J105.8, R107.1
unnamed: J105.9, R108.1
unnamed: J105.11, R109.1
VDD: C101.1, J106.A4 (VBUS), J106.A9 (VBUS), J106.B4 (VBUS), J106.B9 (VBUS), R101.2, U302.5 (VP); also elsewhere on the board

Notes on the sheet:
Bottom
PinHeader_Display
Connectors and mounting Supports for Display
USB_Protection
Enclousure Holes
Fiducials
SWITCH Select USB/DEGUBBER
TOP
PinSocket_Display

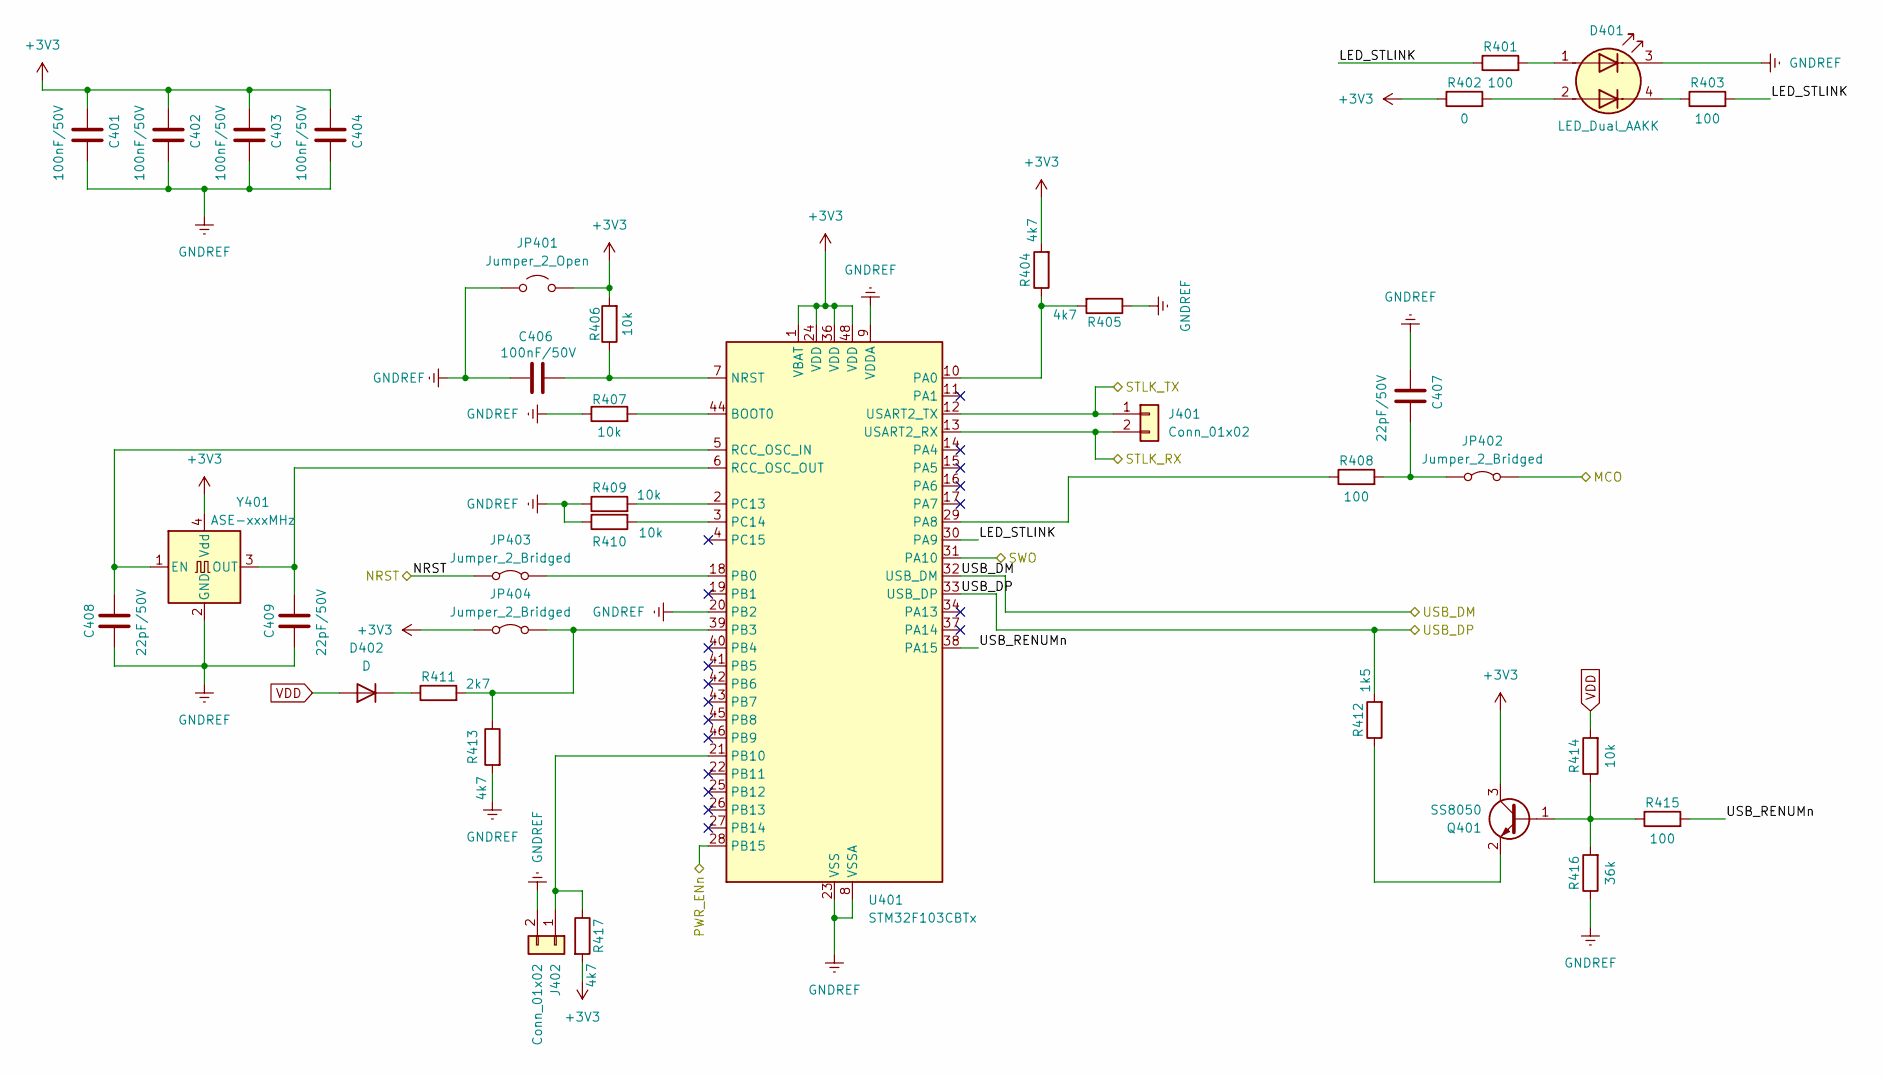
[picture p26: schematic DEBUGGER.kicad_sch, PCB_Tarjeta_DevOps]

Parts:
C401, C402, C403, C404, C406: 100nF/50V; C_0603_1608Metric_Pad1.08x0.95mm_HandSolder
C407, C408, C409: 22pF/50V; C_0603_1608Metric_Pad1.08x0.95mm_HandSolder
D401: LED_Dual_AAKK; LED_Inolux_IN-PI554FCH_PLCC4_5.0x5.0mm_P3.2mm
D402: D; D_SMA_Handsoldering
J401, J402: Conn_01x02; PinHeader_1x02_P2.54mm_Vertical
JP401: Jumper_2_Open; SolderJumper-2_P1.3mm_Open_TrianglePad1.0x1.5mm
JP402, JP403, JP404: Jumper_2_Bridged; SolderJumper-2_P1.3mm_Bridged_Pad1.0x1.5mm
Q401: SS8050; SOT-23W_Handsoldering
R401, R403, R408, R415: 100; R_0603_1608Metric_Pad0.98x0.95mm_HandSolder
R402: 0; R_0603_1608Metric_Pad0.98x0.95mm_HandSolder
R404, R405, R413, R417: 4k7; R_0603_1608Metric_Pad0.98x0.95mm_HandSolder
R406, R407, R409, R410, R414: 10k; R_0603_1608Metric_Pad0.98x0.95mm_HandSolder
R411: 2k7; R_0603_1608Metric_Pad0.98x0.95mm_HandSolder
R412: 1k5; R_0603_1608Metric_Pad0.98x0.95mm_HandSolder
R416: 36k; R_0603_1608Metric_Pad0.98x0.95mm_HandSolder
U401: STM32F103CBTx; LQFP-48_7x7mm_P0.5mm
Y401: ASE-xxxMHz; Oscillator_SMD_EuroQuartz_XO53-4Pin_5.0x3.2mm_HandSoldering

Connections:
+3V3: C401.1, C402.1, C403.1, C404.1, JP401.2 (B), JP404.1 (A), Q401.3 (C), R402.1, R404.2, R406.2, R417.2, U401.1 (VBAT), U401.24 (VDD), U401.36 (VDD), U401.48 (VDD), Y401.4 (Vdd); also elsewhere on the board
/DEBUGGER/LED_STLINK: R401.1, R403.2, U401.30 (PA9)
/DEBUGGER/MCO: JP402.2 (B); also elsewhere on the board
/DEBUGGER/NRST: JP403.1 (A); also elsewhere on the board
/DEBUGGER/PWR_ENn: U401.28 (PB15); also elsewhere on the board
/DEBUGGER/STLK_RX: J401.2, U401.13 (USART2_RX); also elsewhere on the board
/DEBUGGER/STLK_TX: J401.1, U401.12 (USART2_TX); also elsewhere on the board
/DEBUGGER/SWO: U401.31 (PA10); also elsewhere on the board
/DEBUGGER/USB_DM: U401.32 (USB_DM); also elsewhere on the board
/DEBUGGER/USB_DP: R412.2, U401.33 (USB_DP); also elsewhere on the board
/DEBUGGER/USB_RENUMn: R415.2, U401.38 (PA15)
GNDREF: C401.2, C402.2, C403.2, C404.2, C406.2, C407.1, C408.2, C409.2, D401.3 (K1), J402.2, JP401.1 (A), R405.1, R407.1, R409.1, R410.1, R413.2, R416.1, U401.8 (VSSA), U401.9 (VDDA), U401.20 (PB2), U401.23 (VSS), U401.35 (VSS), U401.47 (VSS), Y401.2 (GND); also elsewhere on the board
unnamed: D401.1 (A1), R401.2
unnamed: D401.2 (A2), R402.2
unnamed: D401.4 (K2), R403.1
unnamed: D402.1 (K), R411.1
unnamed: J402.1, R417.1, U401.21 (PB10)
unnamed: C407.2, JP402.1 (A), R408.2
unnamed: JP403.2 (B), U401.18 (PB0)
unnamed: JP404.2 (B), R411.2, R413.1, U401.39 (PB3)
unnamed: Q401.1 (B), R414.1, R415.1, R416.2
unnamed: Q401.2 (E), R412.1
unnamed: R407.2, U401.44 (BOOT0)
unnamed: C406.1, R406.1, U401.7 (NRST)
unnamed: R404.1, R405.2, U401.10 (PA0)
unnamed: R408.1, U401.29 (PA8)
unnamed: R409.2, U401.2 (PC13)
unnamed: R410.2, U401.3 (PC14)
unnamed: C408.1, U401.5 (RCC_OSC_IN), Y401.1 (EN)
unnamed: C409.1, U401.6 (RCC_OSC_OUT), Y401.3 (OUT)
VDD: D402.2 (A), R414.2; also elsewhere on the board

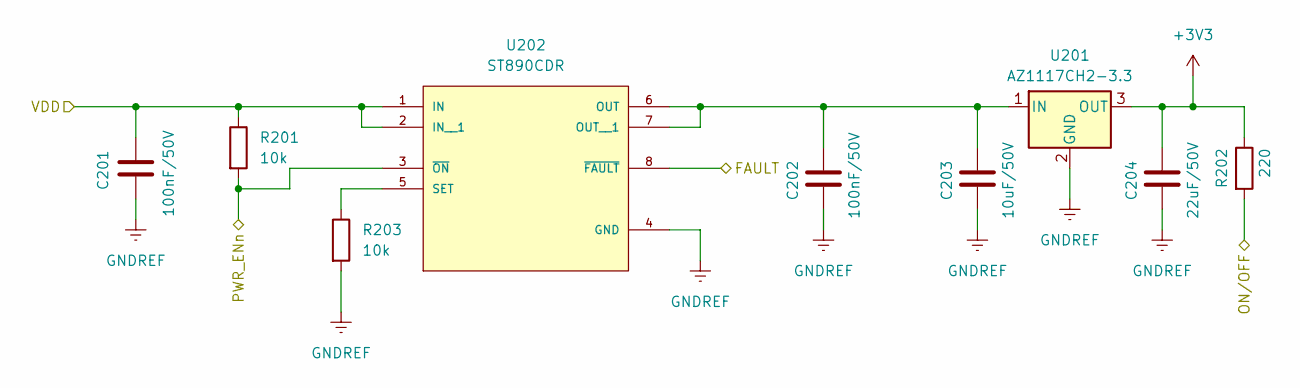
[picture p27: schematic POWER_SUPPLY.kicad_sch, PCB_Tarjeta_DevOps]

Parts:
C201, C202: 100nF/50V; C_0603_1608Metric_Pad1.08x0.95mm_HandSolder
C203: 10uF/50V; C_0603_1608Metric_Pad1.08x0.95mm_HandSolder
C204: 22uF/50V; C_0603_1608Metric_Pad1.08x0.95mm_HandSolder
R201, R203: 10k; R_0603_1608Metric_Pad0.98x0.95mm_HandSolder
R202: 220; R_0603_1608Metric_Pad0.98x0.95mm_HandSolder
U201: AZ1117CH2-3.3; TO-252-2
U202: ST890CDR; SOIC127P600X175-8N; PARTREV 10

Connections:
+3V3: C204.1, R202.1, U201.3 (OUT); also elsewhere on the board
/DEBUGGER/PWR_ENn: R201.2, U202.3 (~ON); also elsewhere on the board
/POWER_SUPPLY/FAULT: U202.8 (~FAULT); also elsewhere on the board
/POWER_SUPPLY/ON/OFF: R202.2; also elsewhere on the board
GNDREF: C201.2, C202.2, C203.2, C204.2, R203.2, U201.2 (GND), U202.4 (GND); also elsewhere on the board
unnamed: C202.1, C203.1, U201.1 (IN), U202.6 (OUT), U202.7 (OUT__1)
unnamed: R203.1, U202.5 (SET)
VDD: C201.1, R201.1, U202.1 (IN), U202.2 (IN__1); also elsewhere on the board

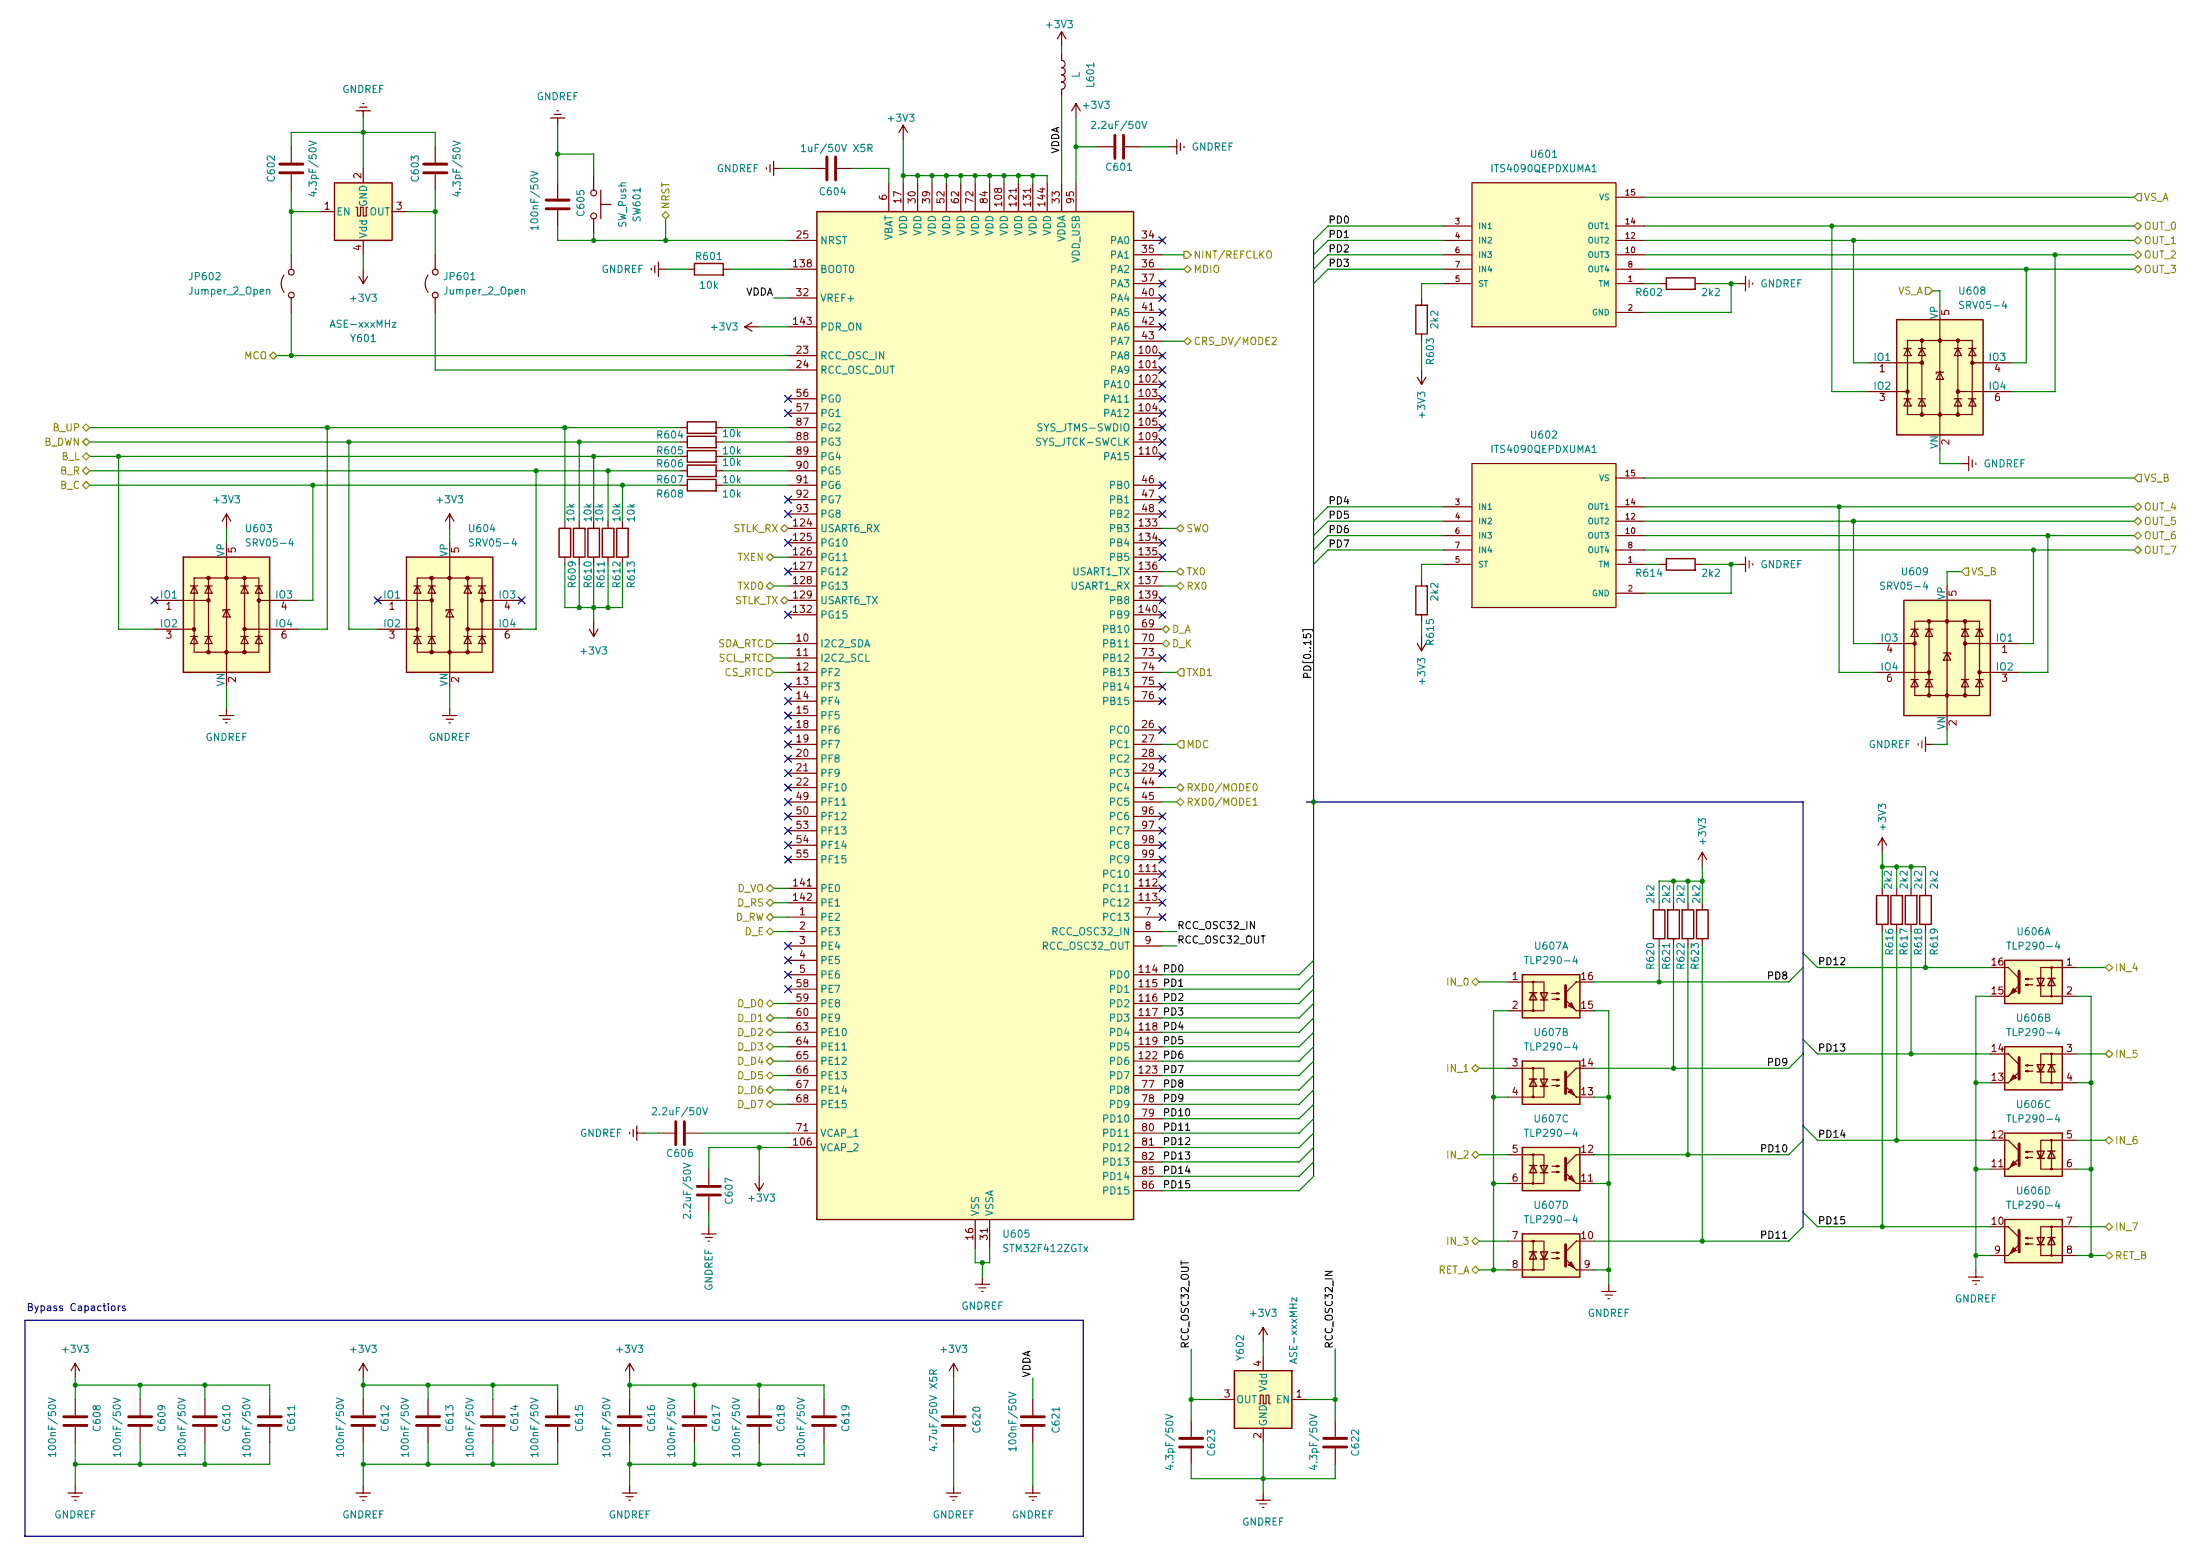
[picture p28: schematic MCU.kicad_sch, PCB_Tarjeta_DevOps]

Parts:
C601, C606, C607: 2.2uF/50V; C_0603_1608Metric_Pad1.08x0.95mm_HandSolder
C602, C603, C622, C623: 4.3pF/50V; C_0603_1608Metric_Pad1.08x0.95mm_HandSolder
C604: 1uF/50V X5R; C_0603_1608Metric_Pad1.08x0.95mm_HandSolder
C605, C608, C609, C610, C611, C612, C613, C614, C615, C616, C617, C618, C619, C621: 100nF/50V; C_0603_1608Metric_Pad1.08x0.95mm_HandSolder
C620: 4.7uF/50V X5R; C_0603_1608Metric_Pad1.08x0.95mm_HandSolder
JP601, JP602: Jumper_2_Open; SolderJumper-2_P1.3mm_Open_TrianglePad1.0x1.5mm
L601: L; L_0603_1608Metric_Pad1.05x0.95mm_HandSolder
R601, R604, R605, R606, R607, R608, R609, R610, R611, R612, R613: 10k; R_0603_1608Metric_Pad0.98x0.95mm_HandSolder
R602, R603, R614, R615, R616, R617, R618, R619, R620, R621, R622, R623: 2k2; R_0603_1608Metric_Pad0.98x0.95mm_HandSolder
SW601: SW_Push; SW_PUSH_6mm_H5mm
U601, U602: ITS4090QEPDXUMA1; SOP65P600X115-15N
U603, U604, U608, U609: SRV05-4; SOT-23-6
U605: STM32F412ZGTx; LQFP-144_20x20mm_P0.5mm
U606, U607: TLP290-4; SOP-16_4.4x10.4mm_P1.27mm
Y601, Y602: ASE-xxxMHz; Oscillator_SMD_EuroQuartz_XO53-4Pin_5.0x3.2mm_HandSoldering

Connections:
+3V3: C601.1, C607.2, C608.1, C609.1, C610.1, C611.1, C612.1, C613.1, C614.1, C615.1, C616.1, C617.1, C618.1, C619.1, C620.2, L601.1, R603.1, R609.1, R610.1, R611.1, R612.1, R613.1, R615.1, R616.2, R617.2, R618.2, R619.2, R620.2, R621.2, R622.2, R623.2, U603.5 (VP), U604.5 (VP), U605.17 (VDD), U605.30 (VDD), U605.39 (VDD), U605.52 (VDD), U605.62 (VDD), U605.72 (VDD), U605.84 (VDD), U605.95 (VDD_USB), U605.106 (VCAP_2), U605.108 (VDD), U605.121 (VDD), U605.131 (VDD), U605.143 (PDR_ON), U605.144 (VDD), Y601.4 (Vdd), Y602.4 (Vdd); also elsewhere on the board
/DEBUGGER/MCO: JP602.1 (A), U605.23 (RCC_OSC_IN); also elsewhere on the board
/DEBUGGER/NRST: C605.1, SW601.2, U605.25 (NRST); also elsewhere on the board
/DEBUGGER/STLK_RX: U605.124 (USART6_RX); also elsewhere on the board
/DEBUGGER/STLK_TX: U605.129 (USART6_TX); also elsewhere on the board
/DEBUGGER/SWO: U605.133 (PB3); also elsewhere on the board
/D_A: U605.69 (PB10); also elsewhere on the board
/D_D0: U605.59 (PE8); also elsewhere on the board
/D_D1: U605.60 (PE9); also elsewhere on the board
/D_D2: U605.63 (PE10); also elsewhere on the board
/D_D3: U605.64 (PE11); also elsewhere on the board
/D_D4: U605.65 (PE12); also elsewhere on the board
/D_D5: U605.66 (PE13); also elsewhere on the board
/D_D6: U605.67 (PE14); also elsewhere on the board
/D_D7: U605.68 (PE15); also elsewhere on the board
/D_E: U605.2 (PE3); also elsewhere on the board
/D_K: U605.70 (PB11); also elsewhere on the board
/D_RS: U605.142 (PE1); also elsewhere on the board
/D_RW: U605.1 (PE2); also elsewhere on the board
/D_VO: U605.141 (PE0); also elsewhere on the board
/ETHERNET/CRS_DV/MODE2: U605.43 (PA7); also elsewhere on the board
/ETHERNET/MDC: U605.27 (PC1); also elsewhere on the board
/ETHERNET/MDIO: U605.36 (PA2); also elsewhere on the board
/ETHERNET/NINT/REFCLKO: U605.35 (PA1); also elsewhere on the board
/ETHERNET/RXD0/MODE0: U605.44 (PC4); also elsewhere on the board
/ETHERNET/RXD1/MODE1: U605.45 (PC5); also elsewhere on the board
/ETHERNET/TXD0: U605.128 (PG13); also elsewhere on the board
/ETHERNET/TXD1: U605.74 (PB13); also elsewhere on the board
/ETHERNET/TXEN: U605.126 (PG11); also elsewhere on the board
/MCU/B_C: R608.1, R613.2, U603.4 (IO3); also elsewhere on the board
/MCU/B_DWN: R605.1, R610.2, U604.3 (IO2); also elsewhere on the board
/MCU/B_L: R606.1, R611.2, U603.3 (IO2); also elsewhere on the board
/MCU/B_R: R607.1, R612.2, U604.6 (IO4); also elsewhere on the board
/MCU/B_UP: R604.1, R609.2, U603.6 (IO4); also elsewhere on the board
/MCU/CS_RTC: U605.12 (PF2); also elsewhere on the board
/MCU/IN_0: U607.1; also elsewhere on the board
/MCU/IN_1: U607.3; also elsewhere on the board
/MCU/IN_2: U607.5; also elsewhere on the board
/MCU/IN_3: U607.7; also elsewhere on the board
/MCU/IN_4: U606.1; also elsewhere on the board
/MCU/IN_5: U606.3; also elsewhere on the board
/MCU/IN_6: U606.5; also elsewhere on the board
/MCU/IN_7: U606.7; also elsewhere on the board
/MCU/OUT_0: U601.14 (OUT1), U608.3 (IO2); also elsewhere on the board
/MCU/OUT_1: U601.12 (OUT2), U608.1 (IO1); also elsewhere on the board
/MCU/OUT_2: U601.10 (OUT3), U608.6 (IO4); also elsewhere on the board
/MCU/OUT_3: U601.8 (OUT4), U608.4 (IO3); also elsewhere on the board
/MCU/OUT_4: U602.14 (OUT1), U609.6 (IO4); also elsewhere on the board
/MCU/OUT_5: U602.12 (OUT2), U609.4 (IO3); also elsewhere on the board
/MCU/OUT_6: U602.10 (OUT3), U609.3 (IO2); also elsewhere on the board
/MCU/OUT_7: U602.8 (OUT4), U609.1 (IO1); also elsewhere on the board
/MCU/PD0: U601.3 (IN1), U605.114 (PD0)
/MCU/PD1: U601.4 (IN2), U605.115 (PD1)
/MCU/PD2: U601.6 (IN3), U605.116 (PD2)
/MCU/PD3: U601.7 (IN4), U605.117 (PD3)
/MCU/PD4: U602.3 (IN1), U605.118 (PD4)
/MCU/PD5: U602.4 (IN2), U605.119 (PD5)
/MCU/PD6: U602.6 (IN3), U605.122 (PD6)
/MCU/PD7: U602.7 (IN4), U605.123 (PD7)
/MCU/PD8: R620.1, U605.77 (PD8), U607.16
/MCU/PD9: R621.1, U605.78 (PD9), U607.14
/MCU/PD10: R622.1, U605.79 (PD10), U607.12
/MCU/PD11: R623.1, U605.80 (PD11), U607.10
/MCU/PD12: R619.1, U605.81 (PD12), U606.16
/MCU/PD13: R618.1, U605.82 (PD13), U606.14
/MCU/PD14: R617.1, U605.85 (PD14), U606.12
/MCU/PD15: R616.1, U605.86 (PD15), U606.10
/MCU/RCC_OSC32_IN: C622.1, U605.8 (RCC_OSC32_IN), Y602.1 (EN)
/MCU/RCC_OSC32_OUT: C623.1, U605.9 (RCC_OSC32_OUT), Y602.3 (OUT)
/MCU/RET_A: U607.2, U607.4, U607.6, U607.8; also elsewhere on the board
/MCU/RET_B: U606.2, U606.4, U606.6, U606.8; also elsewhere on the board
/MCU/RX0: U605.137 (USART1_RX); also elsewhere on the board
/MCU/SCL_RTC: U605.11 (I2C2_SCL); also elsewhere on the board
/MCU/SDA_RTC: U605.10 (I2C2_SDA); also elsewhere on the board
/MCU/TX0: U605.136 (USART1_TX); also elsewhere on the board
/MCU/VDDA: C621.2, L601.2, U605.32 (VREF+), U605.33 (VDDA)
/MCU/VS_A: U601.15 (VS), U608.5 (VP); also elsewhere on the board
/MCU/VS_B: U602.15 (VS), U609.5 (VP); also elsewhere on the board
GNDREF: C601.2, C602.2, C603.2, C604.1, C605.2, C606.1, C607.1, C608.2, C609.2, C610.2, C611.2, C612.2, C613.2, C614.2, C615.2, C616.2, C617.2, C618.2, C619.2, C620.1, C621.1, C622.2, C623.2, R601.1, R602.2, R614.2, SW601.1, U601.2 (GND), U602.2 (GND), U603.2 (VN), U604.2 (VN), U605.16 (VSS), U605.31 (VSSA), U605.38 (VSS), U605.51 (VSS), U605.61 (VSS), U605.83 (VSS), U605.94 (VSS), U605.107 (VSS), U605.120 (VSS), U605.130 (VSS), U606.9, U606.11, U606.13, U606.15, U607.9, U607.11, U607.13, U607.15, U608.2 (VN), U609.2 (VN), Y601.2 (GND), Y602.2 (GND); also elsewhere on the board
unnamed: JP601.1 (A), U605.24 (RCC_OSC_OUT)
unnamed: C603.1, JP601.2 (B), Y601.3 (OUT)
unnamed: C602.1, JP602.2 (B), Y601.1 (EN)
unnamed: R603.2, U601.5 (ST)
unnamed: R602.1, U601.1 (TM)
unnamed: R615.2, U602.5 (ST)
unnamed: R614.1, U602.1 (TM)
unnamed: R601.2, U605.138 (BOOT0)
unnamed: R604.2, U605.87 (PG2)
unnamed: R605.2, U605.88 (PG3)
unnamed: R606.2, U605.89 (PG4)
unnamed: R607.2, U605.90 (PG5)
unnamed: R608.2, U605.91 (PG6)
unnamed: C604.2, U605.6 (VBAT)
unnamed: C606.2, U605.71 (VCAP_1)

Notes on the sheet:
Bypass Capactiors

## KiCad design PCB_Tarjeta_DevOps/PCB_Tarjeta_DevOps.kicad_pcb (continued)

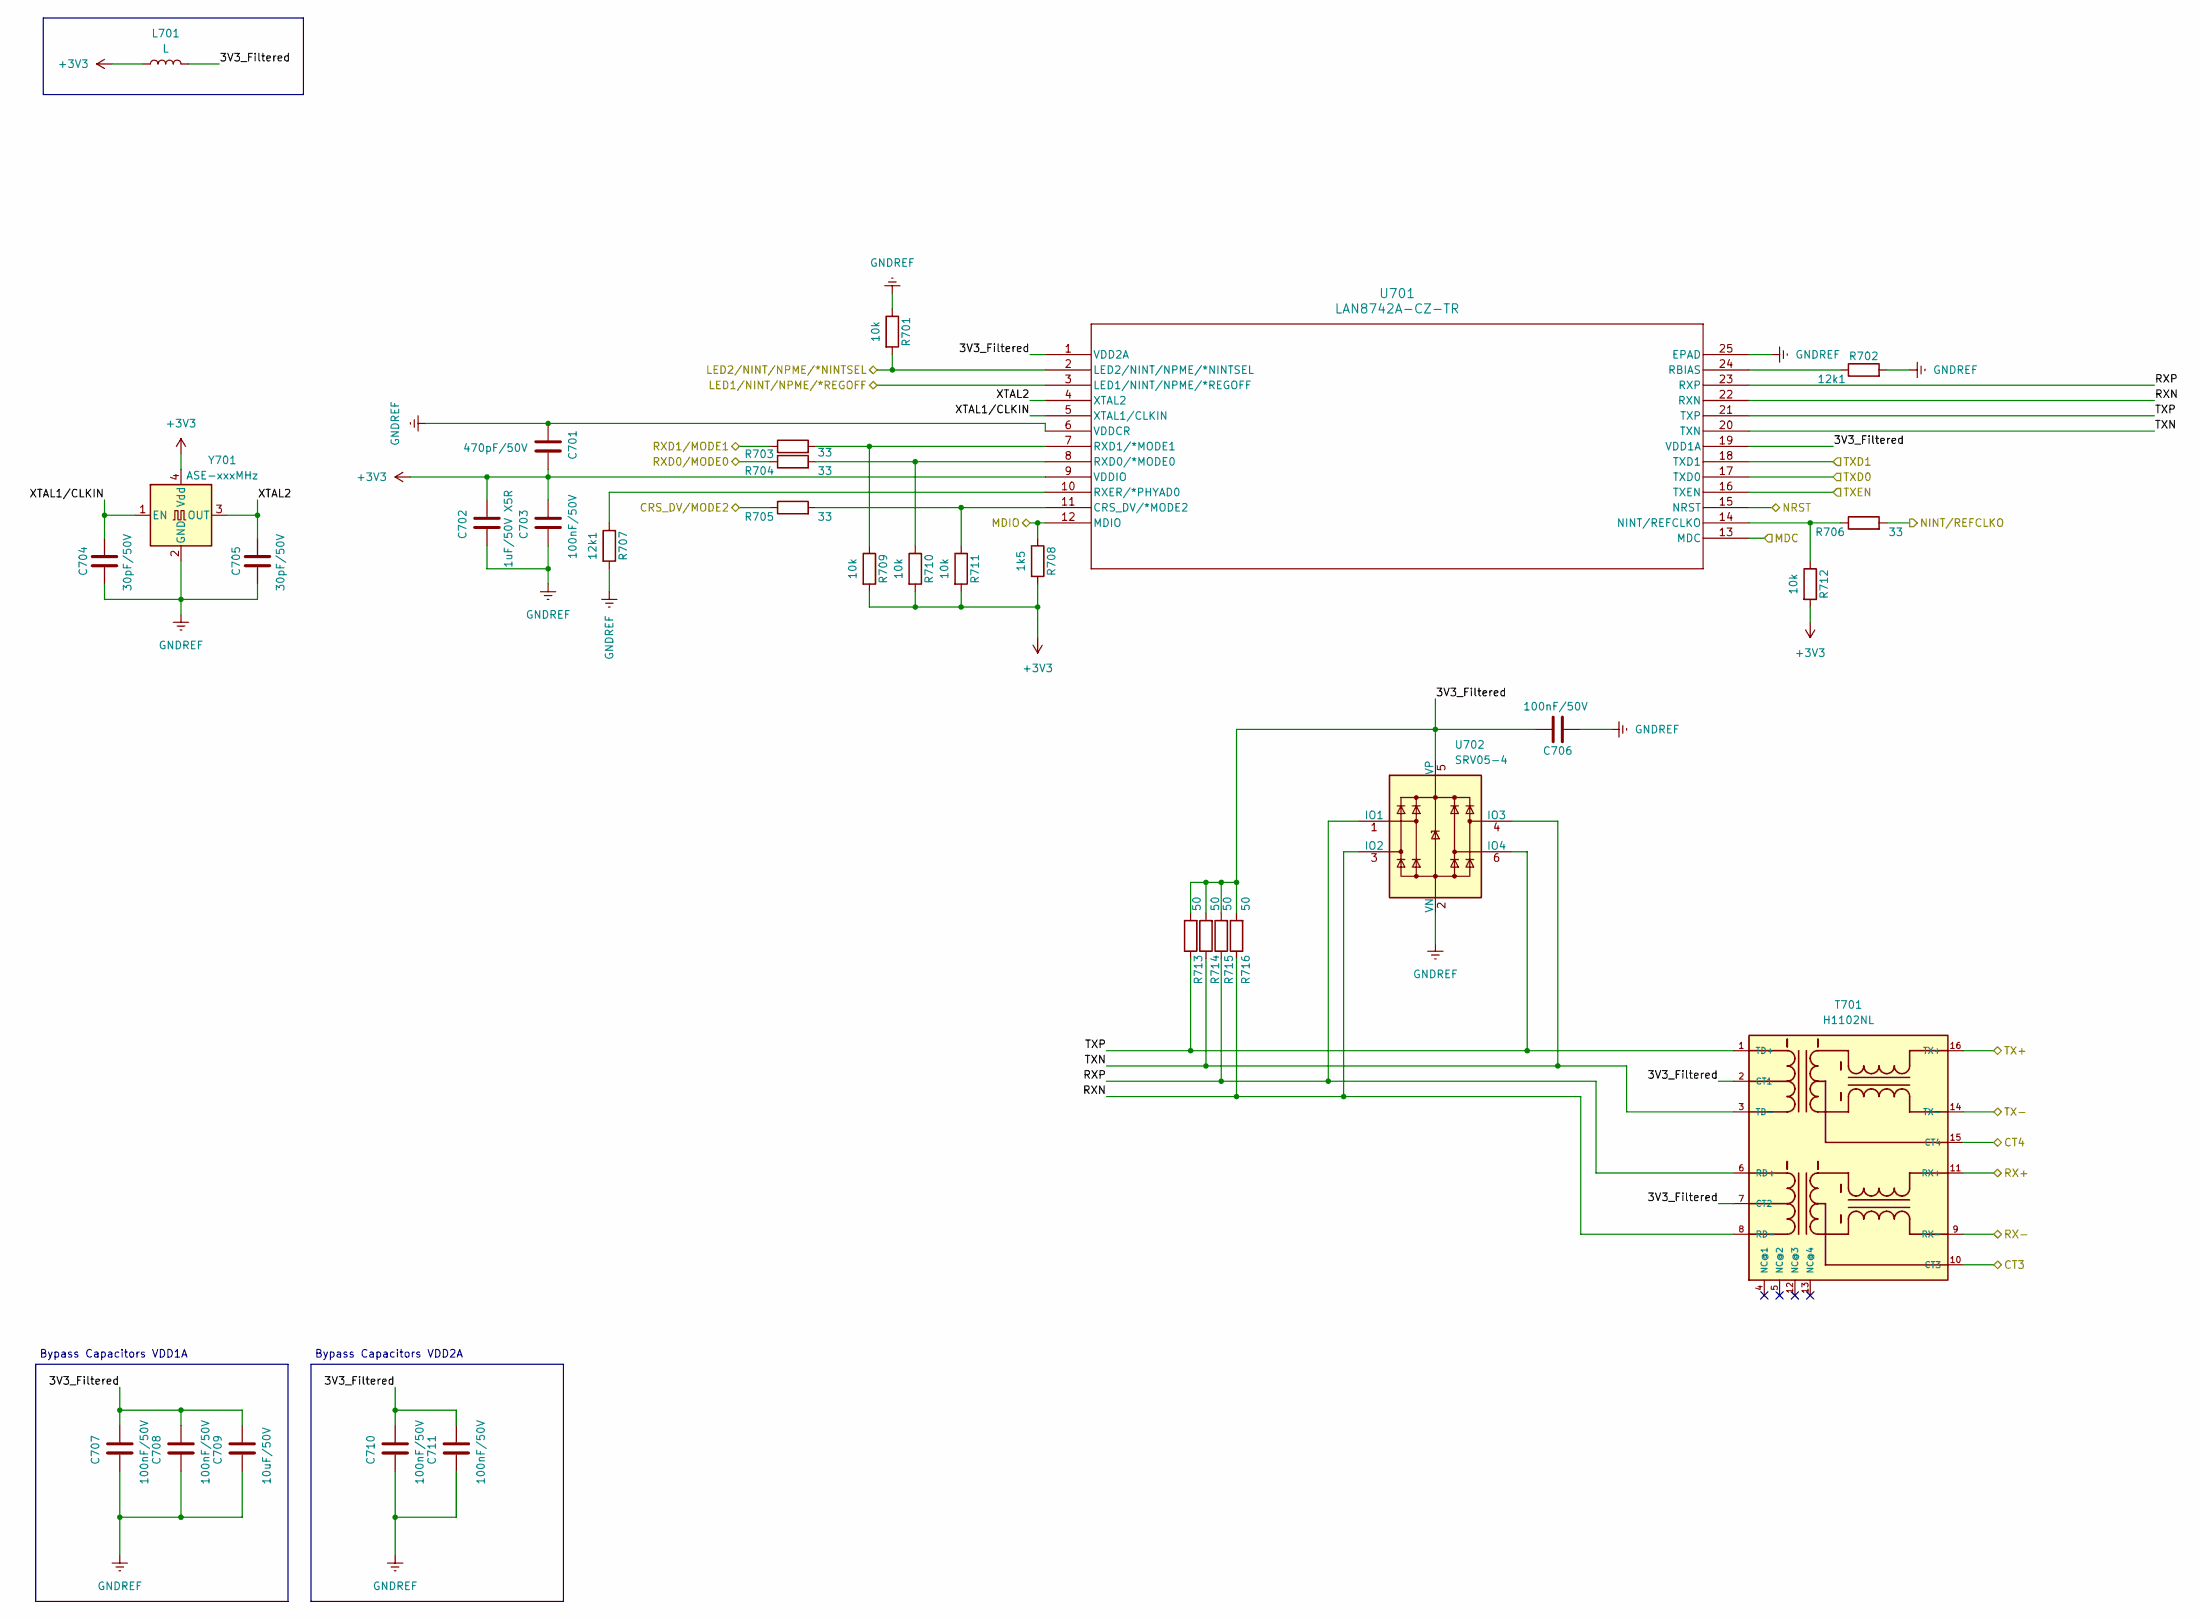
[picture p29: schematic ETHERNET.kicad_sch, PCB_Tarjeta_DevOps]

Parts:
C701: 470pF/50V; C_0603_1608Metric_Pad1.08x0.95mm_HandSolder
C702: 1uF/50V X5R; C_0603_1608Metric_Pad1.08x0.95mm_HandSolder
C703, C706, C707, C708, C710, C711: 100nF/50V; C_0603_1608Metric_Pad1.08x0.95mm_HandSolder
C704, C705: 30pF/50V; C_0603_1608Metric_Pad1.08x0.95mm_HandSolder
C709: 10uF/50V; C_0603_1608Metric_Pad1.08x0.95mm_HandSolder
L701: L; L_0603_1608Metric_Pad1.05x0.95mm_HandSolder
R701, R709, R710, R711, R712: 10k; R_0603_1608Metric_Pad0.98x0.95mm_HandSolder
R702, R707: 12k1; R_0603_1608Metric_Pad0.98x0.95mm_HandSolder
R703, R704, R705, R706: 33; R_0603_1608Metric_Pad0.98x0.95mm_HandSolder
R708: 1k5; R_0603_1608Metric_Pad0.98x0.95mm_HandSolder
R713, R714, R715, R716: 50; R_0603_1608Metric_Pad0.98x0.95mm_HandSolder
T701: H1102NL
U701: LAN8742A-CZ-TR; SQFN24_4X4MC_MCH
U702: SRV05-4; SOT-23-6
Y701: ASE-xxxMHz; Oscillator_SMD_EuroQuartz_XO53-4Pin_5.0x3.2mm_HandSoldering

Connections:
+3V3: C701.1, C702.1, C703.1, L701.1, R708.2, R709.2, R710.2, R711.2, R712.2, U701.9 (VDDIO), Y701.4 (Vdd); also elsewhere on the board
/DEBUGGER/NRST: U701.15 (NRST); also elsewhere on the board
/ETHERNET/3V3_Filtered: C706.1, C707.1, C708.1, C709.1, C710.1, C711.1, L701.2, R713.2, R714.2, R715.2, R716.2, T701.2 (CT1), T701.7 (CT2), U701.1 (VDD2A), U701.19 (VDD1A), U702.5 (VP)
/ETHERNET/CRS_DV/MODE2: R705.1; also elsewhere on the board
/ETHERNET/CT3: T701.10 (CT3); also elsewhere on the board
/ETHERNET/CT4: T701.15 (CT4); also elsewhere on the board
/ETHERNET/LED1/NINT/NPME/*REGOFF: U701.3 (LED1/NINT/NPME/*REGOFF); also elsewhere on the board
/ETHERNET/LED2/NINT/NPME/*NINTSEL: R701.2, U701.2 (LED2/NINT/NPME/*NINTSEL); also elsewhere on the board
/ETHERNET/MDC: U701.13 (MDC); also elsewhere on the board
/ETHERNET/MDIO: R708.1, U701.12 (MDIO); also elsewhere on the board
/ETHERNET/NINT/REFCLKO: R706.2; also elsewhere on the board
/ETHERNET/RX+: T701.11 (RX+); also elsewhere on the board
/ETHERNET/RX-: T701.9 (RX-); also elsewhere on the board
/ETHERNET/RXD0/MODE0: R704.1; also elsewhere on the board
/ETHERNET/RXD1/MODE1: R703.1; also elsewhere on the board
/ETHERNET/RXN: R716.1, T701.8 (RD-), U701.22 (RXN), U702.3 (IO2)
/ETHERNET/RXP: R715.1, T701.6 (RD+), U701.23 (RXP), U702.1 (IO1)
/ETHERNET/TX+: T701.16 (TX+); also elsewhere on the board
/ETHERNET/TX-: T701.14 (TX-); also elsewhere on the board
/ETHERNET/TXD0: U701.17 (TXD0); also elsewhere on the board
/ETHERNET/TXD1: U701.18 (TXD1); also elsewhere on the board
/ETHERNET/TXEN: U701.16 (TXEN); also elsewhere on the board
/ETHERNET/TXN: R714.1, T701.3 (TD-), U701.20 (TXN), U702.4 (IO3)
/ETHERNET/TXP: R713.1, T701.1 (TD+), U701.21 (TXP), U702.6 (IO4)
/ETHERNET/XTAL1/CLKIN: C704.1, U701.5 (XTAL1/CLKIN), Y701.1 (EN)
/ETHERNET/XTAL2: C705.1, U701.4 (XTAL2), Y701.3 (OUT)
GNDREF: C701.2, C702.2, C703.2, C704.2, C705.2, C706.2, C707.2, C708.2, C709.2, C710.2, C711.2, R701.1, R702.2, R707.2, U701.6 (VDDCR), U701.25 (EPAD), U702.2 (VN), Y701.2 (GND); also elsewhere on the board
unnamed: R705.2, R711.1, U701.11 (CRS_DV/*MODE2)
unnamed: R706.1, R712.1, U701.14 (NINT/REFCLKO)
unnamed: R702.1, U701.24 (RBIAS)
unnamed: R704.2, R710.1, U701.8 (RXD0/*MODE0)
unnamed: R703.2, R709.1, U701.7 (RXD1/*MODE1)
unnamed: R707.1, U701.10 (RXER/*PHYAD0)

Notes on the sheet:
Bypass Capacitors VDD1A
Bypass Capacitors VDD2A

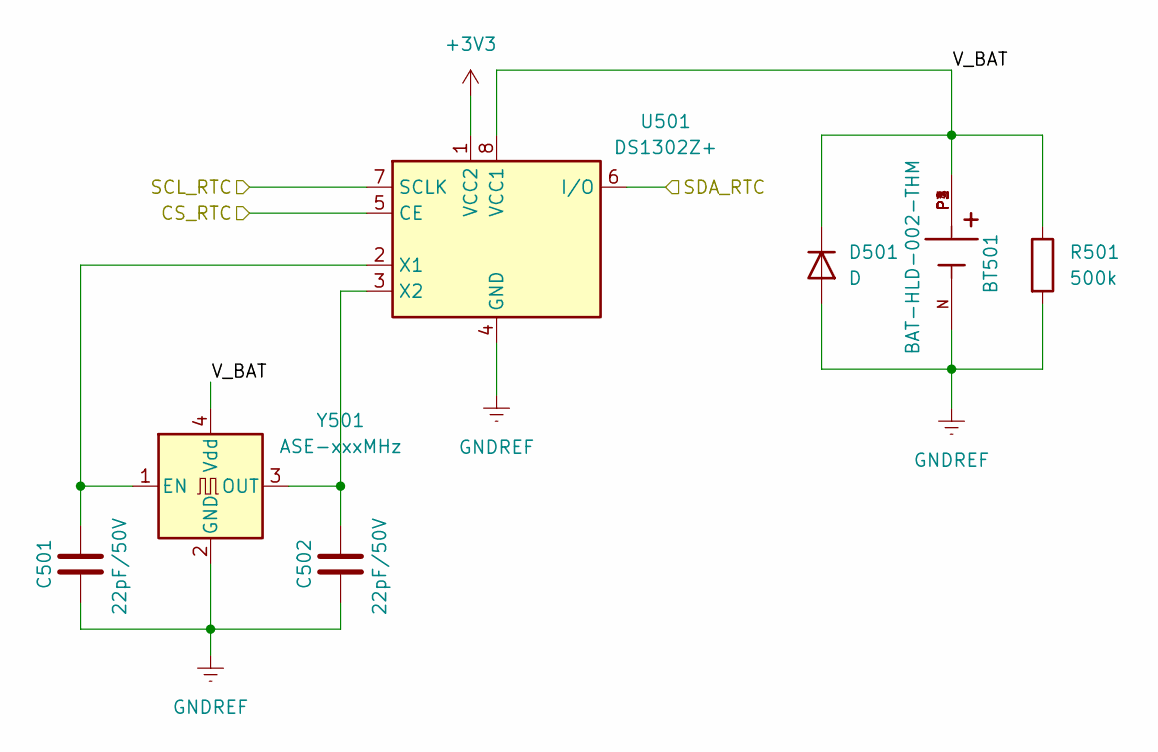
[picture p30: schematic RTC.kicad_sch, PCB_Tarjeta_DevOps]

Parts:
BT501: BAT-HLD-002-THM; BAT_BAT-HLD-002-THM; PARTREV C
C501, C502: 22pF/50V; C_0603_1608Metric_Pad1.08x0.95mm_HandSolder
D501: D; D_SMA_Handsoldering
R501: 500k; R_0603_1608Metric_Pad0.98x0.95mm_HandSolder
U501: DS1302Z+; DIP-8_W7.62mm_Socket_LongPads
Y501: ASE-xxxMHz; Oscillator_SMD_EuroQuartz_XO53-4Pin_5.0x3.2mm_HandSoldering

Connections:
+3V3: U501.1 (VCC2); also elsewhere on the board
/MCU/CS_RTC: U501.5 (CE); also elsewhere on the board
/MCU/SCL_RTC: U501.7 (SCLK); also elsewhere on the board
/MCU/SDA_RTC: U501.6 (I/O); also elsewhere on the board
/RTC/V_BAT: BT501.P1, BT501.P2, BT501.P3, BT501.P4, D501.1 (K), R501.1, U501.8 (VCC1), Y501.4 (Vdd)
GNDREF: BT501.N, C501.2, C502.2, D501.2 (A), R501.2, U501.4 (GND), Y501.2 (GND); also elsewhere on the board
unnamed: C501.1, U501.2 (X1), Y501.1 (EN)
unnamed: C502.1, U501.3 (X2), Y501.3 (OUT)

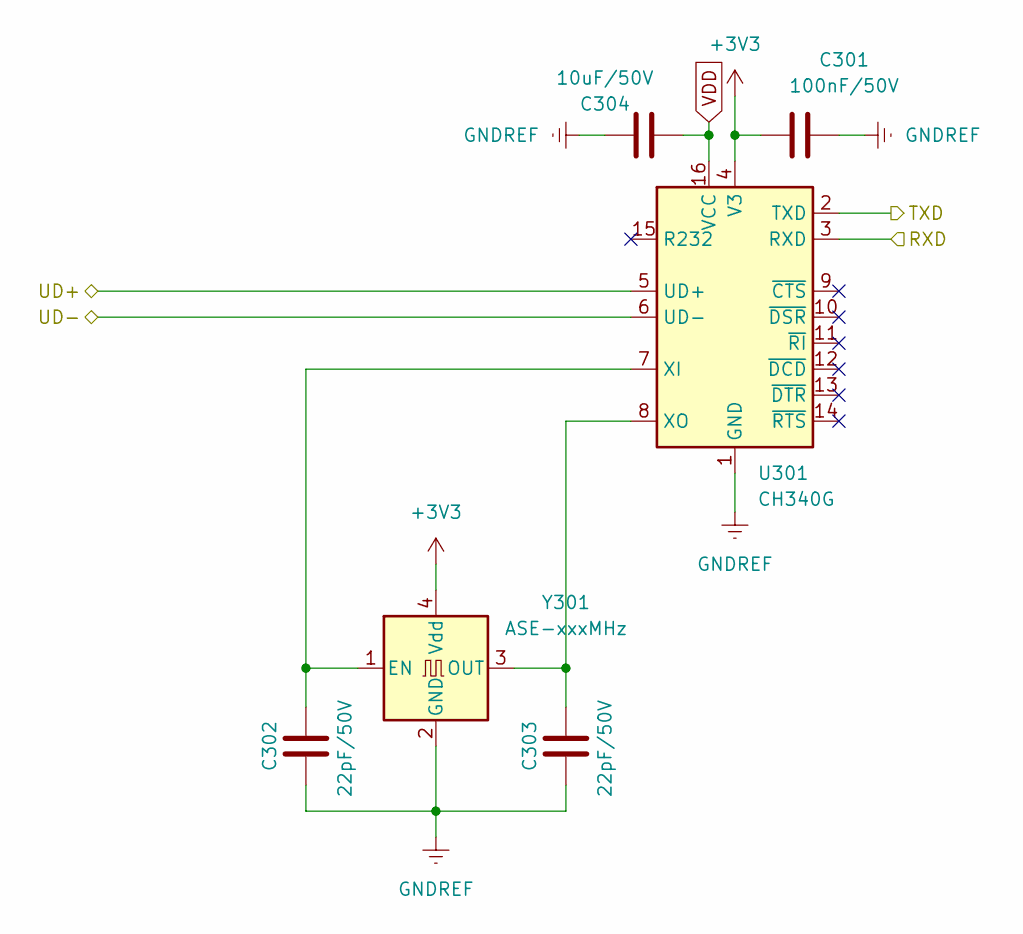
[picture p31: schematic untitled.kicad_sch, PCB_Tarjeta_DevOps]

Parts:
C301: 100nF/50V; C_0603_1608Metric_Pad1.08x0.95mm_HandSolder
C302, C303: 22pF/50V; C_0603_1608Metric_Pad1.08x0.95mm_HandSolder
C304: 10uF/50V; C_0603_1608Metric_Pad1.08x0.95mm_HandSolder
U301: CH340G; SOIC-16_3.9x9.9mm_P1.27mm
Y301: ASE-xxxMHz; Oscillator_SMD_EuroQuartz_XO53-4Pin_5.0x3.2mm_HandSoldering

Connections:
+3V3: C301.1, U301.4 (V3), Y301.4 (Vdd); also elsewhere on the board
/MCU/RX0: U301.3 (RXD); also elsewhere on the board
/MCU/TX0: U301.2 (TXD); also elsewhere on the board
/USB-UART/UD+: U301.5 (UD+); also elsewhere on the board
/USB-UART/UD-: U301.6 (UD-); also elsewhere on the board
GNDREF: C301.2, C302.2, C303.2, C304.2, U301.1 (GND), Y301.2 (GND); also elsewhere on the board
unnamed: C302.1, U301.7 (XI), Y301.1 (EN)
unnamed: C303.1, U301.8 (XO), Y301.3 (OUT)
VDD: C304.1, U301.16 (VCC); also elsewhere on the board

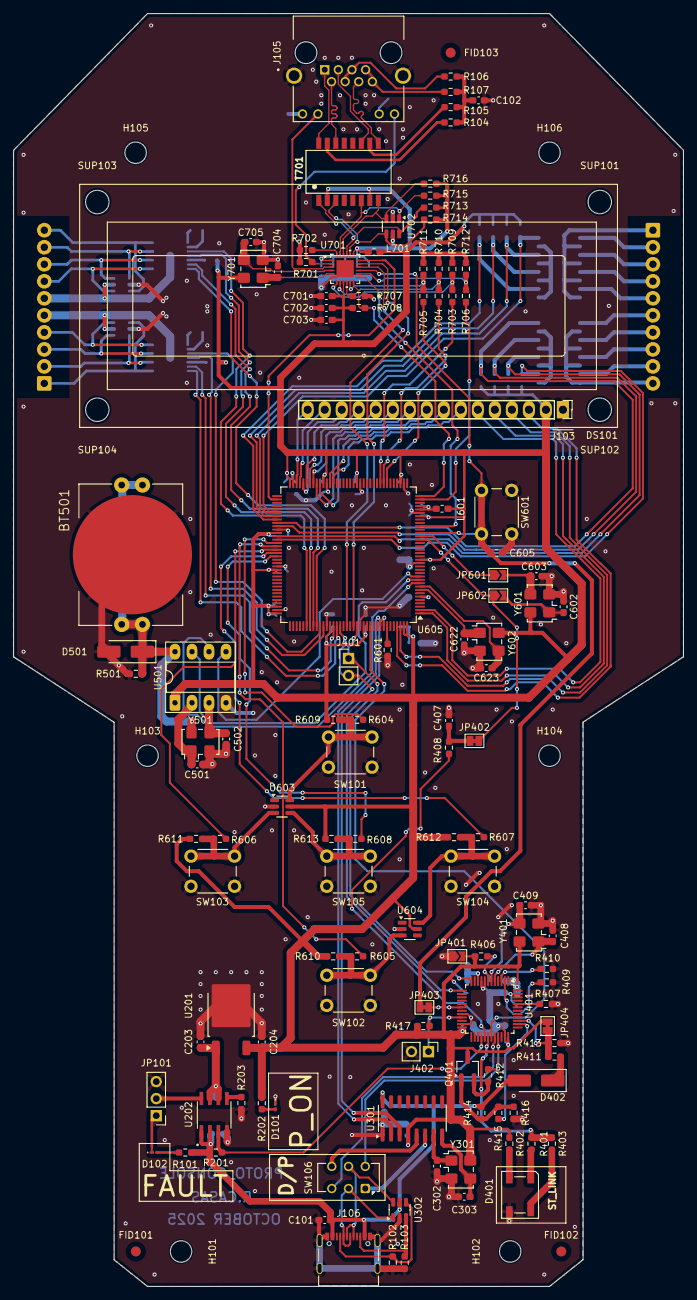
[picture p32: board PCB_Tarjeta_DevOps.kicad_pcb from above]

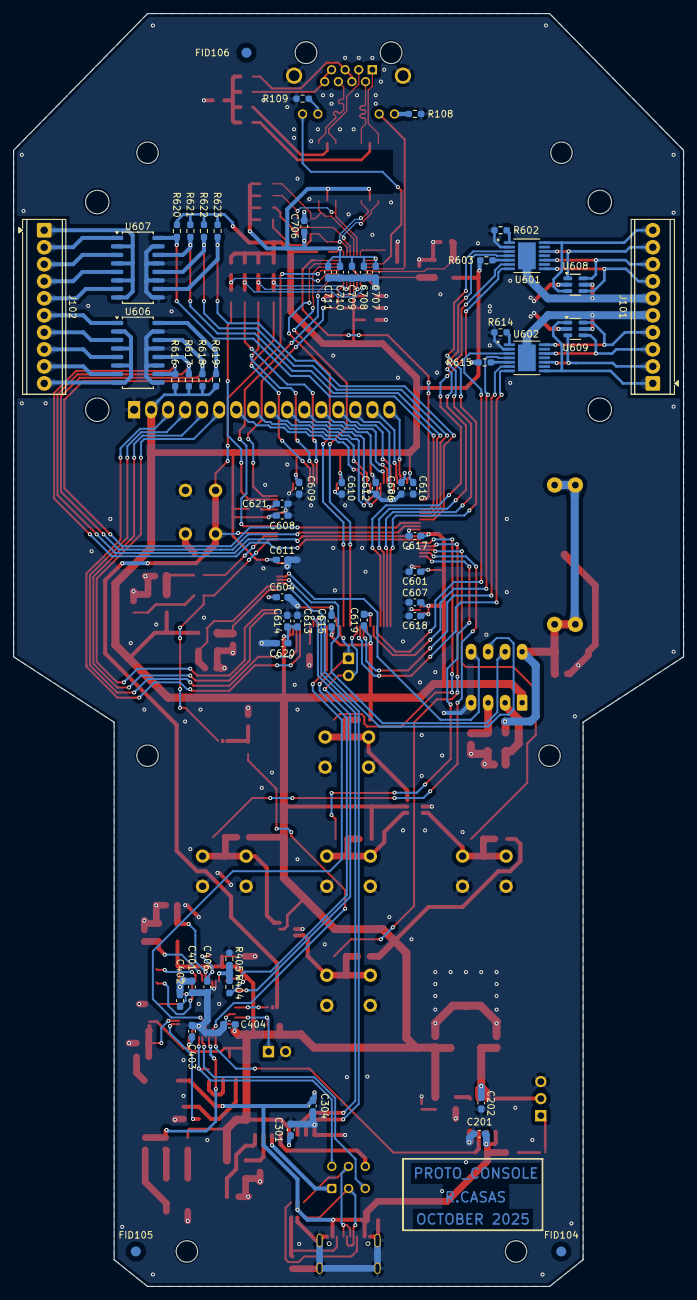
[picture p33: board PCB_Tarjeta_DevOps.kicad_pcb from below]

Board: 2 copper layers, 100.0 x 190.0 mm, 195 parts (60 on the bottom side), 161 nets.
